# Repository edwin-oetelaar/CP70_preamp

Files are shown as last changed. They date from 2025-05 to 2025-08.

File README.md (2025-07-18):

# Yamaha CP70 Electric Grand Piano - 72 Channel Pre-amplifier Project

https://www.pomeindhoven.nl/

Paviljoen Ongehoorde Muziek
Vestdijk 25 - 5611 CA
Eindhoven

## Project Overview

This repository contains the KiCad project files, documentation, and design decisions for a custom-built 72-channel pre-amplifier designed for a Yamaha CP70 electric grand piano. This project is an open-source initiative developed in collaboration with [Paviljoen Ongehoorde Muziek (POM)](https://www.pomeindhoven.nl/) in Eindhoven, Netherlands, as part of an art project.

The primary goal of this pre-amplifier is to individually buffer and potentially amplify the signals from each of the 72 string pickups of the CP70, providing a high-quality, low-noise output output signal for further amplification to 72 speakers.

**Repository URL:** [https://github.com/edwin-oetelaar/CP70_preamp/tree/main](https://github.com/edwin-oetelaar/CP70_preamp/tree/main)

## Image of the piano

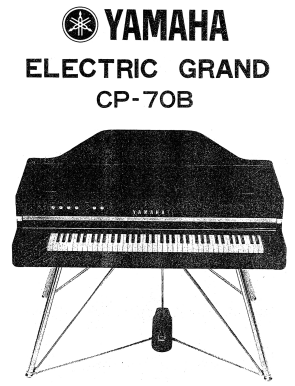
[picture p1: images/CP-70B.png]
piano


## Background

The Yamaha CP70 is an iconic electric grand piano known for its unique sound, derived from real strings and hammers combined with a piezo pickup system.
This project aims to provide a modern, high-fidelity replacement, with 72 separate output channels as an alternative pre-amplifier system.

This pre-amp is designed with the following considerations:
*   **High Input Impedance:** To accurately capture the full tonal character of the CP70 pickups without loading them down.
*   **Low Noise Performance:** Essential for a clean signal, especially with 72 individual channels.
*   **Sufficient Headroom:** To handle the potentially large signal swings from the pickups.
*   **Individual Channel Processing:** Each pickup receives its own pre-amplifier stage.
*   **Modularity:** For ease of assembly, testing, and maintenance.
*   **Open Source:** All design files and documentation are publicly available to encourage learning, modification, accessibility.

## Project Status

[ **TODO: Update this section regularly, e.g., In Design, Prototyping, Tested, In Use** ]

*   Current Version: [e.g., v0.1 - Initial Design]
*   Key Milestones:
    *   [x] Initial schematic design complete.
    *   [x] PCB layout for [16]-channel module complete.
    *   [x] PCB ordered
    *   [x] parts ordered
    *   [ ] First prototype(s) built and tested.
    *   [ ] Full 72-channel system assembled.
    *   [ ] Integration with the CP70 at Paviljoen Ongehoorde Muziek.

## Design Files and Documentation

This repository is structured to include:

*   **/kicad_project:** Contains the KiCad schematic and PCB layout files.
    *   `CP70_preamp.kicad_pro` - Main KiCad project file.
    *   `CP70_preamp.kicad_sch` - Main schematic file.
    *   `CP70_preamp.kicad_pcb` - Main PCB layout file (or individual module files).
    *   `libraries/` - Custom schematic symbols and PCB footprints, if any.
    *   `out1/` - Gerber files for PCB manufacturing (to be added when ready). (file out1.zip sent to JLCPCB)
    *   `bom/` - Bill of Materials (to be added).
*   **/documentation:**
    *   `design_decisions.md` - Detailed explanation of the design choices, component selection, and rationale.
    *   `specifications.md` - Target specifications for the pre-amplifier.
    *   `testing_procedure.md` - (To be added) How to test individual modules and the full system.
    *   Images, block diagrams, and other supporting documents.
*   **/images:** Schematics, photos of prototypes, etc.
*   `README.md` - This file.

# image of version 0.1 printed circuit board

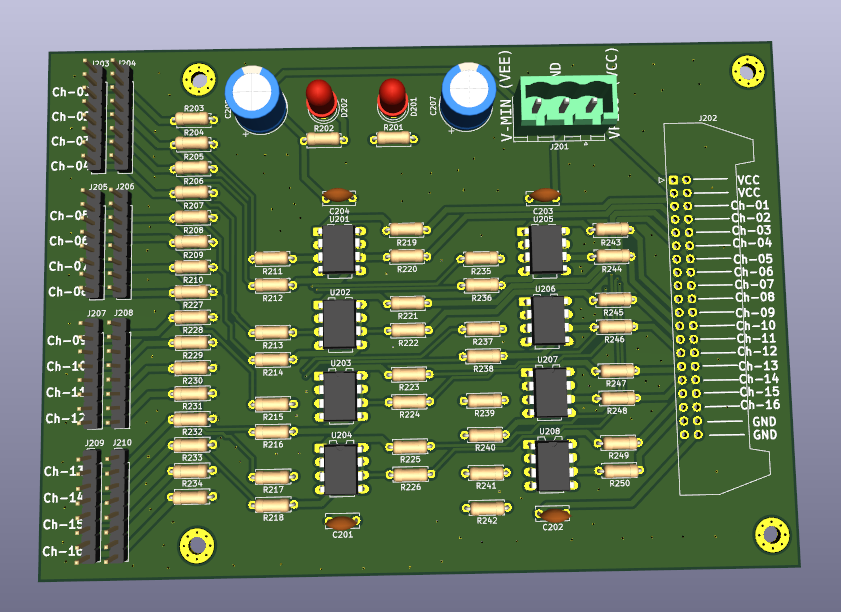
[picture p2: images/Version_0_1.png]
pcb0.1


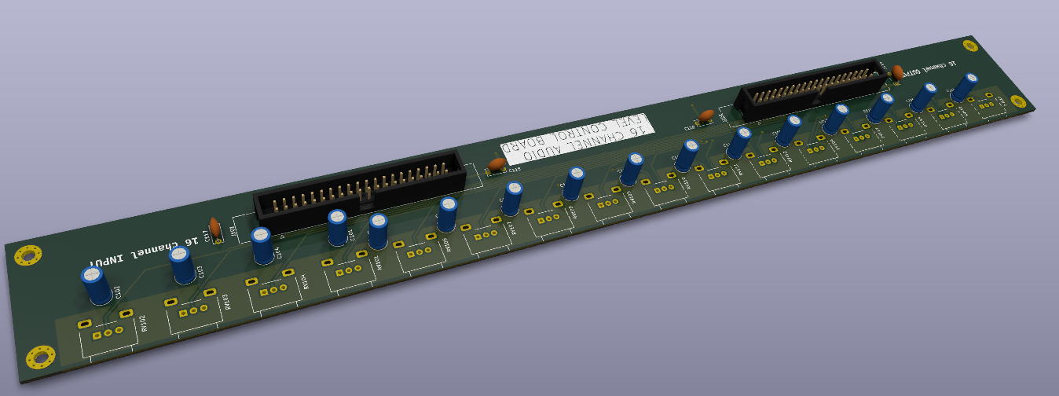
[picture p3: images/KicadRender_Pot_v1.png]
pcbPot0.1

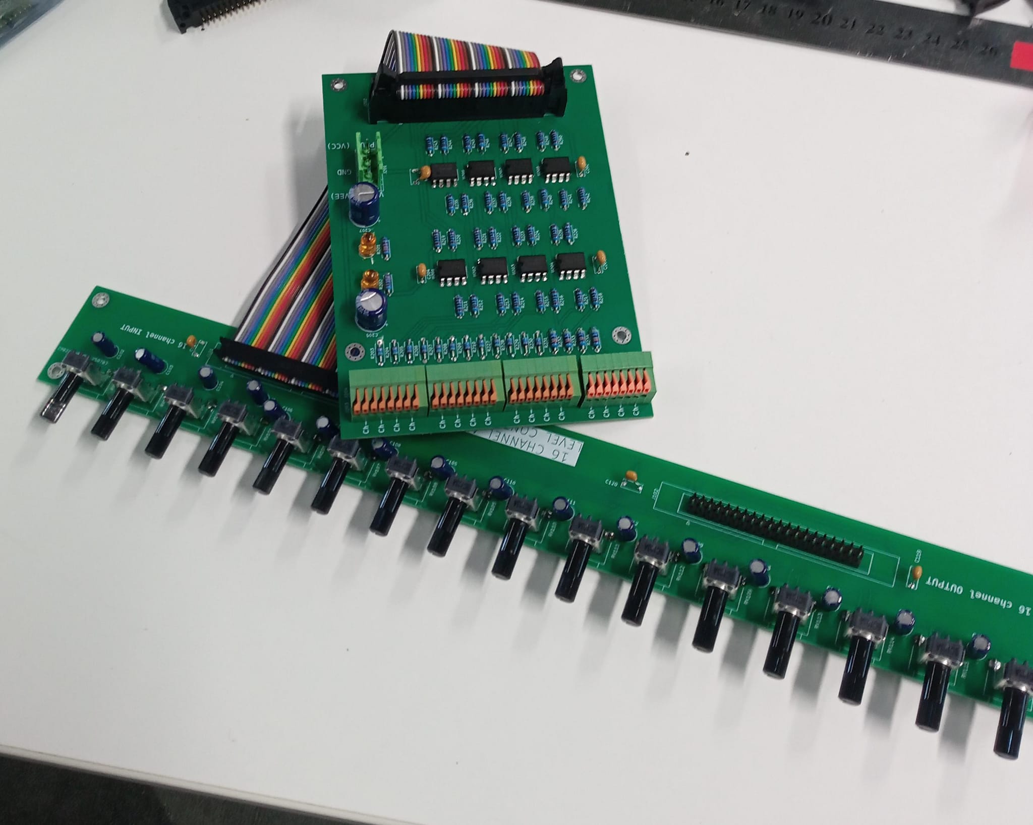
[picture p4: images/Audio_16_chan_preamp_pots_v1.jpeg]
pcb_built_v1


## Key Design Aspects (Summary)

*   **Number of Channels:** 72 (one for each pickup)
*   **Input Stage:** High-impedance buffer for each channel.
    *   Target Input Impedance: 470K Ω
    *   Expected Pickup Output: Up to 45V peak-to-peak in 1 M (requiring input attenuation).
*   **Operational Amplifier:** [e.g., TL072 or similar, specify your choice and link to design_decisions.md]
*   **Power Supply:** Symmetrical (e.g., +/-15V or +/-18V)
*   **Gain:** [e.g., Unity gain buffer, or variable gain via potentiometer - specify and link to design_decisions.md]

More detailed information on architecture, component choices, and trade-offs can be found in `/documentation/design_decisions.md`.

## Getting Started / How to Use

1.  **Clone the repository:**
    ```bash
    git clone https://github.com/edwin-oetelaar/CP70_preamp.git
    cd CP70_preamp
    ```
2.  **Open in KiCad:** Open the `CP70_preamp.kicad_pro` file in KiCad (Latest version).
3.  **Review Schematics and PCB Layout:** Explore the design in the KiCad schematic editor and PCB editor.
4.  **Check Documentation:** Read through the `design_decisions.md` and other documents for a deeper understanding.

## Contributing

This is an open-source project, and contributions or suggestions are welcome! If you have ideas, find bugs, or want to contribute to the design:

1.  **Fork the repository.**
2.  **Create a new branch** for your feature or bug fix.
3.  **Make your changes.**
4.  **Submit a Pull Request** with a clear description of your changes.

You can also open an [Issue](https://github.com/edwin-oetelaar/CP70_preamp/issues) to report bugs or suggest improvements.

## Collaboration

This project is in proud collaboration with:

**Paviljoen Ongehoorde Muziek (POM)**
Vestdijk 25 - 5611 CA Eindhoven
[https://www.pomeindhoven.nl/](https://www.pomeindhoven.nl/)

The pre-amplifier is intended for use in an art project hosted at POM.

## License

This project is licensed under the [MIT License](LICENSE.md) - see the LICENSE.md file for details.

## Contact

For questions or discussions regarding this project, you can contact:
*   Edwin van den Oetelaar - Leave a message in the issue tracker or google my name/email 
*   Or open an issue on this GitHub repository.

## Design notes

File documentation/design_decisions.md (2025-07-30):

# Design Decisions for the CP70 72-Channel Pre-amplifier

**by : Edwin van den Oetelaar**

This document outlines the key design decisions made during the development of the 72-channel pre-amplifier and associated power amplification for the Yamaha CP70 electric grand piano.

## Table of Contents

- [Design Decisions for the CP70 72-Channel Pre-amplifier](#design-decisions-for-the-cp70-72-channel-pre-amplifier)
  - [Table of Contents](#table-of-contents)
  - [1. Overall System Architecture](#1-overall-system-architecture)
  - [2. Pre-amplifier Design Philosophy: Serviceability and Technology Choice](#2-pre-amplifier-design-philosophy-serviceability-and-technology-choice)
  - [3. Pre-amplifier Modularity and Channel Distribution](#3-pre-amplifier-modularity-and-channel-distribution)
  - [4. Front Panel Potentiometer Integration](#4-front-panel-potentiometer-integration)
  - [5. Pre-amplifier Interconnects and Signal Cabling](#5-pre-amplifier-interconnects-and-signal-cabling)
  - [6. Pre-amplifier Power Supply System](#6-pre-amplifier-power-supply-system)
  - [7. Power Amplification Stage](#7-power-amplification-stage)
  - [8. Pre-amplifier Circuit Design (Per Channel)](#8-pre-amplifier-circuit-design-per-channel)
  - [9. Component Selection (Pre-amplifier)](#9-component-selection-pre-amplifier)
  - [System Block Diagram (Mermaid JS - Updated)](#system-block-diagram-mermaid-js---updated)

---

## 1. Overall System Architecture

The system comprises several key stages:
1.  **Pickup Interface:** 72 individual pickups from the Yamaha CP70.
2.  **Pre-amplification:** 72 dedicated pre-amplifier channels to buffer, (optionally) amplify, and provide gain control for each pickup.
3.  **Signal Output:** Buffered signals from the pre-amplifiers are routed out of the piano.
4.  **Power Amplification:** Off-the-shelf Class-D amplifier modules to drive speakers (details below).
5.  **Power Supplies:** Separate, dedicated power supply systems for the pre-amplifiers and power amplifiers.

## 2. Pre-amplifier Design Philosophy: Serviceability and Technology Choice

A core principle for the pre-amplifier design is **serviceability and repairability using standard tools and readily available components.**

*   **Technology Choice:** Through-Hole Technology (THT) will be used exclusively for the pre-amplifier PCBs. This includes THT resistors, capacitors, and IC sockets.
*   **Op-amp Sockets:** All operational amplifiers on the pre-amplifier boards will be socketed. This allows for easy replacement of op-amps without requiring specialized SMT rework equipment (like hot air stations or microscopes).
*   **PCB Material:** Standard double-sided FR4 PCB material will be used.
*   **Potentiometers:** THT potentiometers will be used for front-panel gain control.

This approach ensures that an electronics engineer or skilled technician with standard soldering equipment can maintain and repair the pre-amplifier system effectively.

## 3. Pre-amplifier Modularity and Channel Distribution

The 72 pre-amplifier channels will be distributed across **five (5) identical pre-amplifier Printed Circuit Board (PCB) modules.**

*   Each PCB module will host **sixteen (16) pre-amplifier channels.**
*   This results in a total of 5 modules * 16 channels/module = **80 available pre-amplifier channels.**
*   This provides **8 spare channels** for immediate replacement or future use.

## 4. Front Panel Potentiometer Integration

Individual gain control for each of the 72 active channels will be provided by THT potentiometers mounted on a front panel.

*   **Panel Dimensions:** Approximately 38 cm (width) x 8 cm (height).
*   **Potentiometer Count:** 80. (for each pre-amp channel)
*   **Connection:** Wiring from the potentiometers to the respective pre-amplifier channels on the PCB modules will be required.

## 5. Pre-amplifier Interconnects and Signal Cabling

**Output Signal Cabling (from Pre-amp Modules to External Interface):**

*   **Cable Type:** 40-pin IDC (Insulation-Displacement Connector) ribbon cables will be used *primarily for signal transport*.
*   **Distribution across 5 Cables:** Each of the 5 pre-amplifier modules will route its 16 output signals via one 40-pin ribbon cable.
    *   **Signal Allocation per Cable:** 16 channels * 2 wires/channel (signal + signal ground/return) = 32 wires.
    *   **Remaining Wires per 40-pin Cable:** 40 - 32 = 8 wires. These can be used for additional ground connections or left as spares, but **will not carry main power.**

## 6. Pre-amplifier Power Supply System

A dedicated, robust power supply system will provide symmetrical power (e.g., +/-15V) to the five pre-amplifier PCB modules.

*   **Power Supply Board:** A custom power supply PCB will be designed.
    *   **Technology:** Based on proven linear regulator technology: Transformer -> Diode Bridge Rectifier -> Bulk Filter Capacitors -> Multiple pairs of 7815 (+15V) and 7915 (-15V) linear voltage regulators.
    *   **Outputs:** The power supply board will provide multiple (at least 5, one for each pre-amp module) regulated +/-15V outputs. Each output will be capable of supplying one pre-amp module.
*   **Power Connectors to Pre-amp Modules:**
    *   **Type:** Standard industrial pluggable terminal block connectors.
    *   **Style:** 3-pole (for +Vcc, -Vee, AGND).
    *   **Pitch:** 5.08 mm (e.g., "Combicon" style or similar).
    *   Each pre-amplifier module PCB will have a corresponding 3-pole female connector to receive power.
*   **Rationale:** Separating power distribution from signal cables (ribbon cables) improves noise immunity and allows for more robust power delivery using appropriate gauge wires and connectors.

## 7. Power Amplification Stage

The power amplification stage will utilize off-the-shelf Class-D amplifier modules.

*   **Amplifier Module Choice:** "Chip Original TPA3118 60W DC 12V-24V" modules (commonly available from suppliers like AliExpress) will be purchased in bulk.
*   **Power Output:** Each module is rated for up to 60W (though actual output will depend on supply voltage and load).
*   **Power Supply for Amplifiers:**
    *   A separate 24V DC power supply system will be used for these Class-D modules.
    *   Considering the total power (estimated < 300W for all channels), this might be implemented as a single larger 24V supply or potentially **split into five (5) smaller, independent 24V DC power supplies**, one for each group of power amplifiers corresponding to a pre-amp module's outputs. This can offer better isolation and fault tolerance.
*   **Mounting/Integration Board for TPA3118 Modules:**
    *   To avoid messy point-to-point wiring to the numerous TPA3118 modules, a **custom "motherboard" or "carrier board" PCB** will be designed.
    *   This carrier board will provide:
        *   Sockets or designated mounting points for multiple TPA3118 modules (e.g., 16 per carrier board, aligning with the pre-amp module channel count).
        *   Input connectors to receive the buffered signals from the pre-amplifier ribbon cables.
        *   Output connectors for speakers.
        *   Power distribution and connectors for the 24V DC supply to each TPA3118 module.
    *   This approach significantly improves assembly neatness, reliability, and serviceability of the power amplifier stage.

## 8. Pre-amplifier Circuit Design (Per Channel)

*   [ Placeholder - Details of the THT op-amp circuit, input attenuation, gain stage, etc. ]*

## 9. Component Selection (Pre-amplifier)

*   **Op-amps:** Socketed, THT dual or quad op-amps (e.g., TL072/TL074 or modern equivalents with good audio performance and appropriate voltage ratings).
*   **Resistors:** THT, 1% metal film for signal path.
*   **Capacitors:** THT. Film capacitors for audio coupling (good bi-polar electrolithic caps were chosen), electrolytic/tantalum for power supply bulk filtering, ceramic for local IC decoupling.
*   **Potentiometers:** THT, panel mount, audio taper.
*   **Connectors:**
    *   Inputs from Pickups:  https://www.farnell.com/datasheets/2995445.pdf PCB Spring Type Terminal Blocks (2.54mm pitch)
    *   Outputs to Ribbon Cables: 40-pin IDC male headers on PCB.
    *   Power Input: 3-pole, 5.08mm pitch pluggable terminal block female connector on PCB.
*   [ Placeholder - Other specific components. Refer to Bill of Materials (BOM). ]*

---

## System Block Diagram (Mermaid JS - Updated)

```mermaid
   graph TD
   subgraph Piano_System
        PUs[72 CP70 Pickups] -->|Raw Signals| PreAmp_PCBs
        PreAmp_PCBs -.->|Gain Control Wiring| Pots_Panel
        Pots_Panel -->|User Input| User(User Adjusts Gain)   
        subgraph PreAmp_PCBs["5x Pre-Amplifier PCB Modules (16 THT channels each, Socketed Op-amps)"]
            direction LR
            PCB1[Module 1: 16 Pre-amps]
            PCB2[Module 2: 16 Pre-amps]
            PCB3[Module 3: 16 Pre-amps]
            PCB4[Module 4: 16 Pre-amps]
            PCB5[Module 5: 16 Pre-amps]
        end

        Pots_Panel["Front Panel: 72 THT Potentiometers (38x8cm)"]

        PreAmp_PCBs -->|"Buffered Signals (16 ch/cable via 40-pin Ribbon)"| PowerAmp_Carrier_Boards

        PreAmp_PowerSupply_Board["Pre-amp Power Supply Board (Transformer, Rectifiers, 7815/7915 Regulators)"]
        PreAmp_PowerSupply_Board -->|"Regulated +/-15V (x5 outputs via 3-pole Connectors)"| PreAmp_PCBs
    end

    subgraph Power_Amplification_And_Output
        direction TB
        PowerAmp_Carrier_Boards["5x Power Amp Carrier Boards"]
        subgraph PowerAmp_Carrier_Boards_Details["Details per Carrier Board (example)"]
            direction LR
            Input_From_PreAmp_Ribbon["Ribbon Cable Input (16ch)"] --> TPA_Modules_Mounted
            TPA_Modules_Mounted["16x TPA3118 Class-D Modules (Socketed/Mounted)"] --> Speaker_Outputs[Speaker Outputs]
            Pots_Panel -->|Adjusted levels|TPA_Modules_Mounted 
            PA_Power_Input[24V DC Power Input] --> TPA_Modules_Mounted
        end

        PA_Power_Supplies["5x 24V DC Power Supplies (or single large PSU)"]
        PA_Power_Supplies --> PA_Power_Input

        Speaker_Outputs --> Speakers[Speakers]
    end

    style PUs fill:#22d,stroke:#333,stroke-width:2px
    style PreAmp_PCBs fill:#bbf,stroke:#333,stroke-width:2px
    style Pots_Panel fill:#22d,stroke:#333,stroke-width:2px
    style PreAmp_PowerSupply_Board fill:#orange,stroke:#333,stroke-width:2px
    style PowerAmp_Carrier_Boards fill:#22d,stroke:#333,stroke-width:2px
    style PA_Power_Supplies fill:#orange,stroke:#333,stroke-width:2px
    style Speakers fill:#grey,stroke:#333,stroke-width:2px
```

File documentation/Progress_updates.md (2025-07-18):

---
title: "CP70 Pre-Amp Project Status Report"
date: [YYYY-MM-DD]
version: [vX.Y]
---

## 1. Project Overview  
**Background**  
The Yamaha CP70 is an iconic electric grand piano known for its unique sound, derived from real strings and hammers combined with a piezo pickup system. This project aims to provide a modern, high-fidelity replacement, with 72 separate output channels as an alternative pre-amplifier system.

**Key Objectives**
- High input impedance (470 kΩ) to preserve pickup characteristics
- Very-low noise floor (<20 nV/√Hz)
- Modular 16-channel PCB design
- Open-source hardware documentation

---

## 2. Current Progress  
### 2.1 Version Status
**Current Version**: [v0.3 - Prototype Validation]  
**Project Status**: [🟢 Prototyping | 🟡 Testing | 🔴 In Design]

### 2.2 Key Milestones  
| Milestone | Status | Last Updated |
|---|---|---|
| 16-channel PCB layout | ✅ Completed | 2025-06-10 |
| Input impedance validation | 🟡 In Progress | 2025-07-15 |
| Noise floor measurement | ❌ Pending | - |
| Full 72-channel assembly | ❌ Pending | - |

### 2.3 Technical Updates

**Design Progress**  
- Finalized 2-layer PCB stackup with dedicated ground plane 
- Implemented JFET-based input stage for impedance buffering
- Tested input stage, tested on CP70 pickups, OK (see images)
- Added per-channel gain adjustment (-inf to 0dB)
- designed and built PCB with 16 Audio Log Pots and 40 pin flat cables

**Component Selection**  
- Op-amps: TL072/TL052 (selected for 15nV/√Hz noise)
- Connectors: 3M 2.54mm pitch terminal blocks
- Power: ±15V rails with TL7815 TL7915 regulators

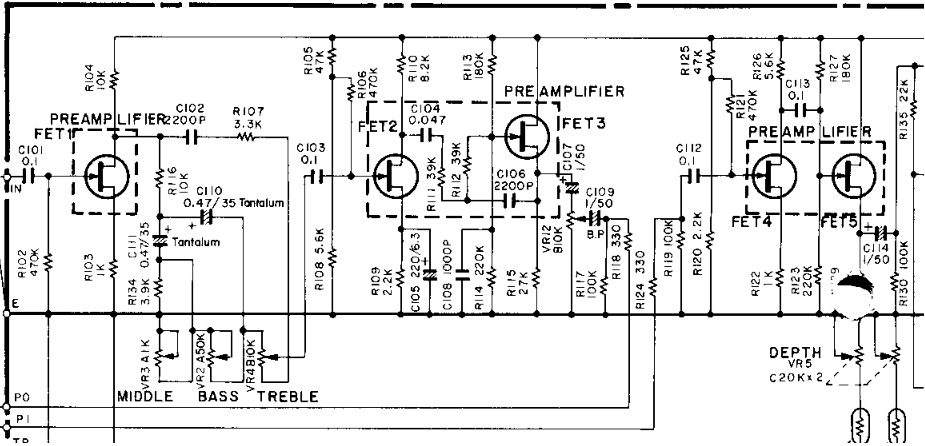
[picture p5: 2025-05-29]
images/cp70_preamp.jpg

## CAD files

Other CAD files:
kicad_project/CP70_line_flatcable/flatcable_PCB_dimensions.FCStd
kicad_project/CP70_line_flatcable/flatcable_PCB_dimensions.dxf

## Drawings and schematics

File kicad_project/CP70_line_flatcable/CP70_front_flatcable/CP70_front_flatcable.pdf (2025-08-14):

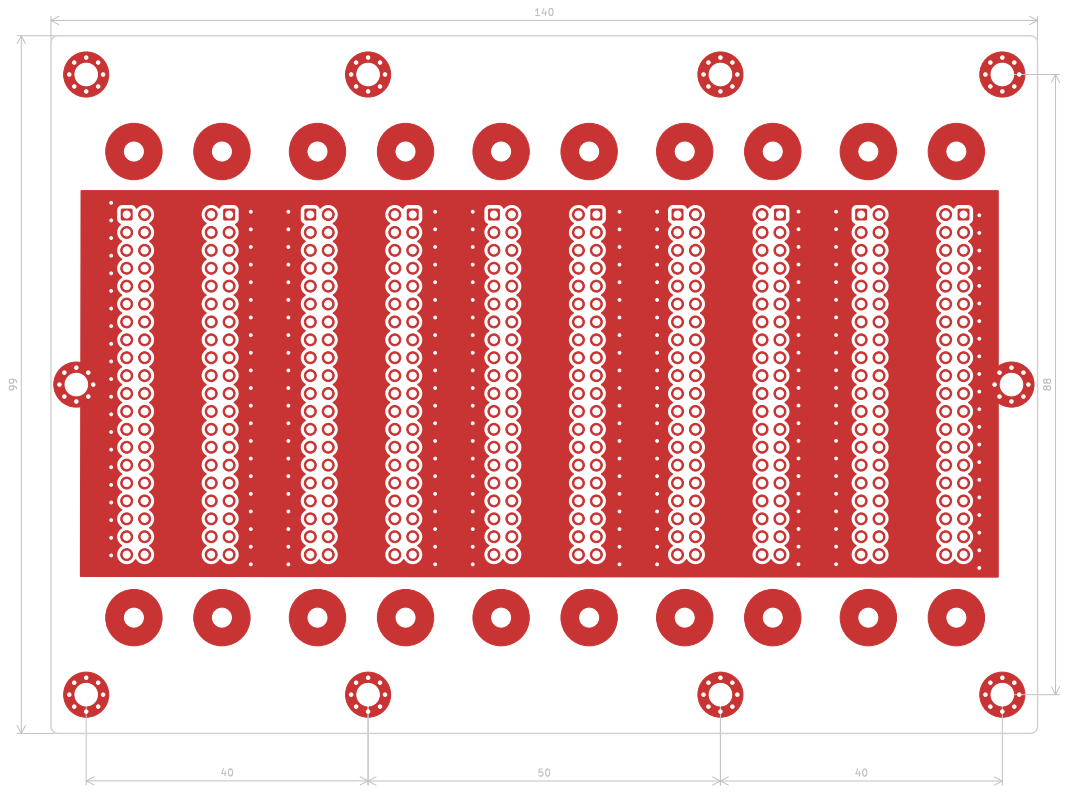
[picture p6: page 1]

Id: 1/9 Title: File: CP70_front_flatcable.kicad_pcb Sheet:

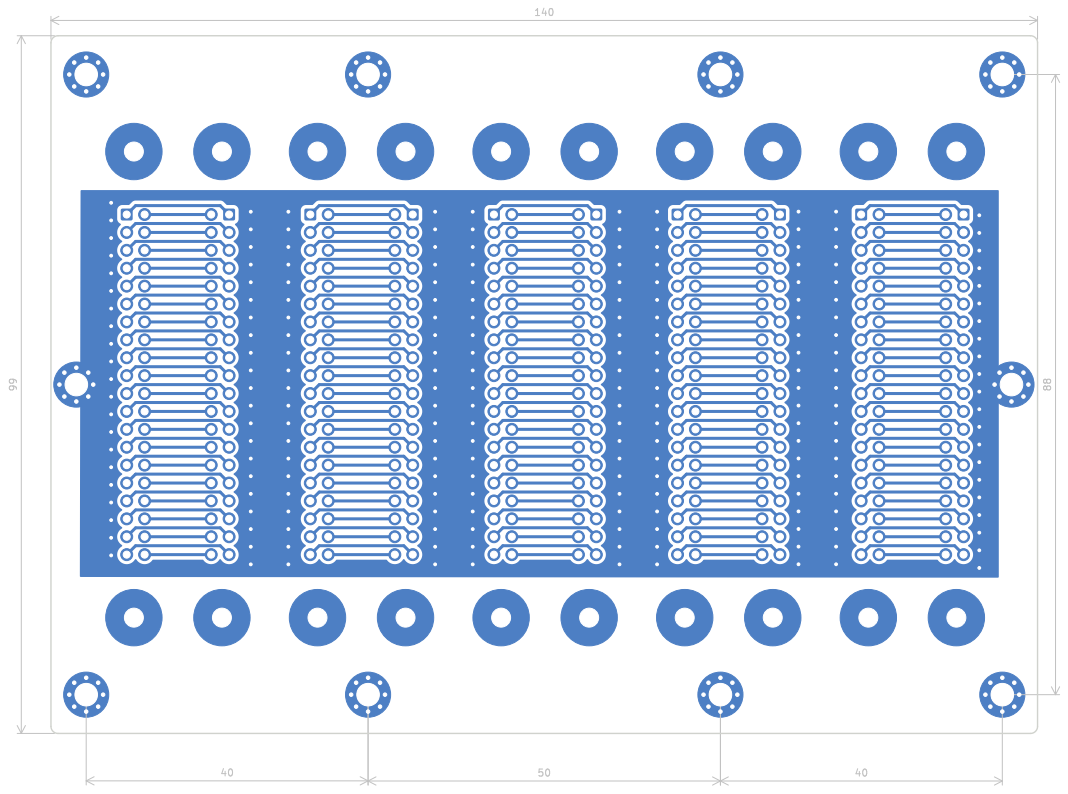
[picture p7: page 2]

Id: 2/9 Title: File: CP70_front_flatcable.kicad_pcb Sheet:

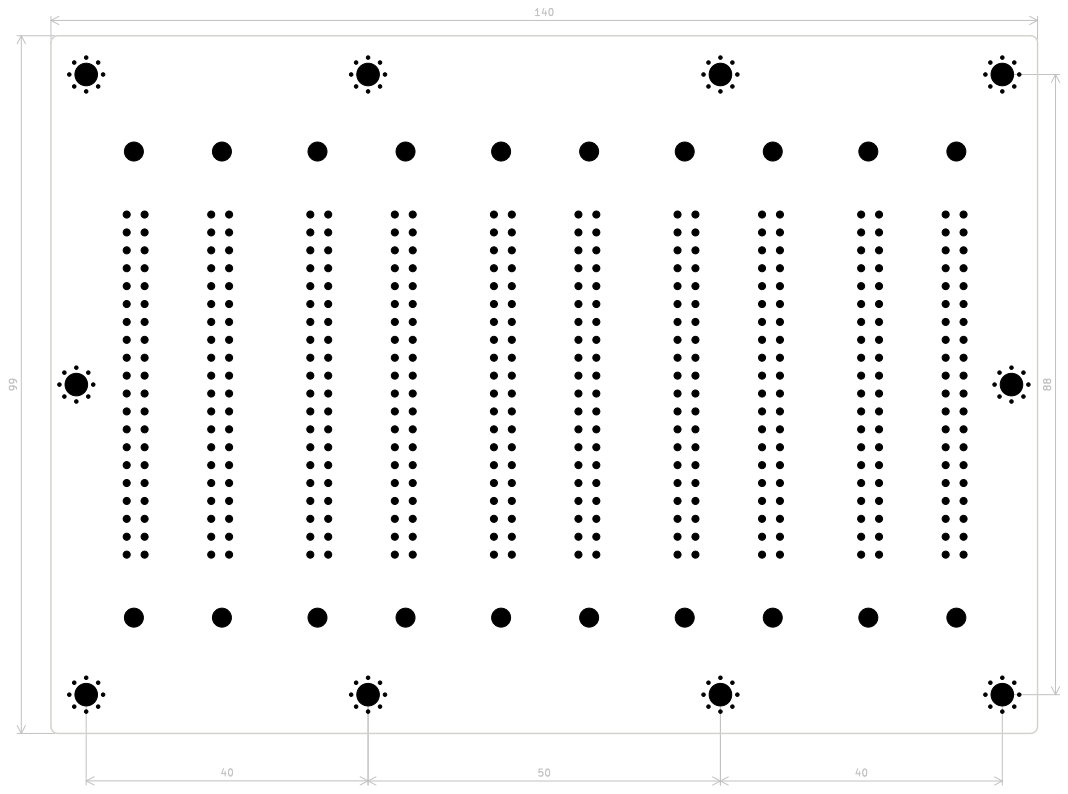
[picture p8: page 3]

Id: 3/9 Title: File: CP70_front_flatcable.kicad_pcb Sheet:

Id: 4/9 Title: File: CP70_front_flatcable.kicad_pcb Sheet:

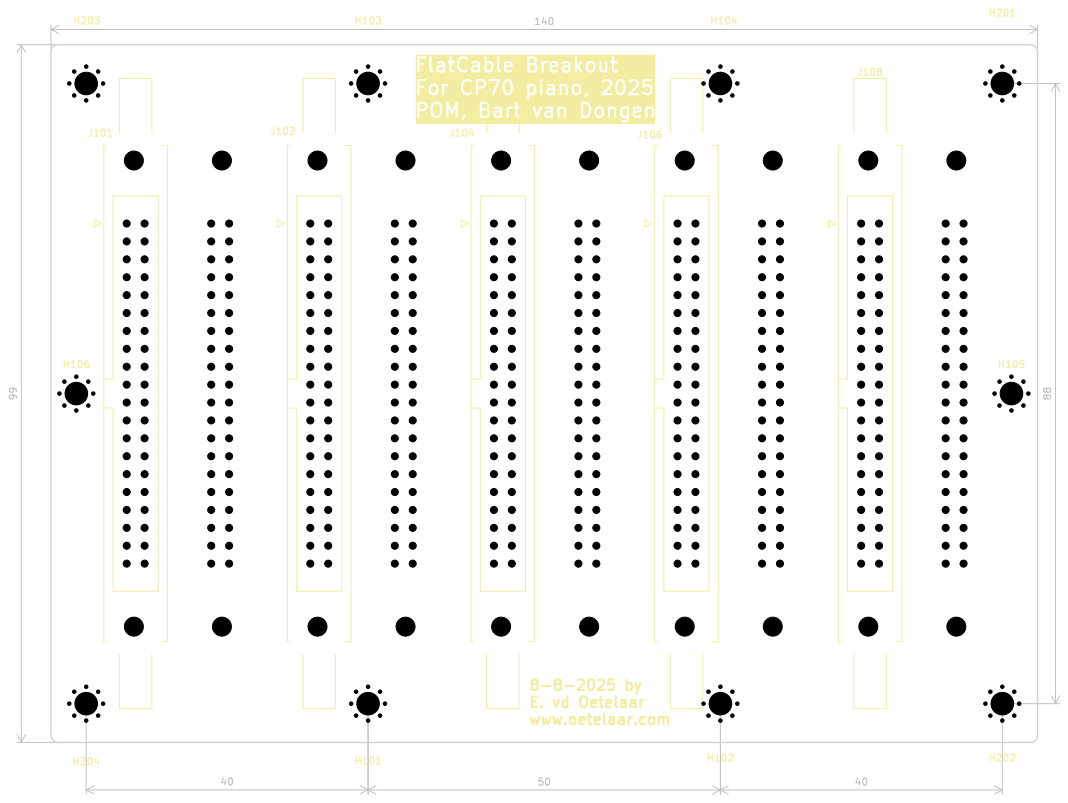
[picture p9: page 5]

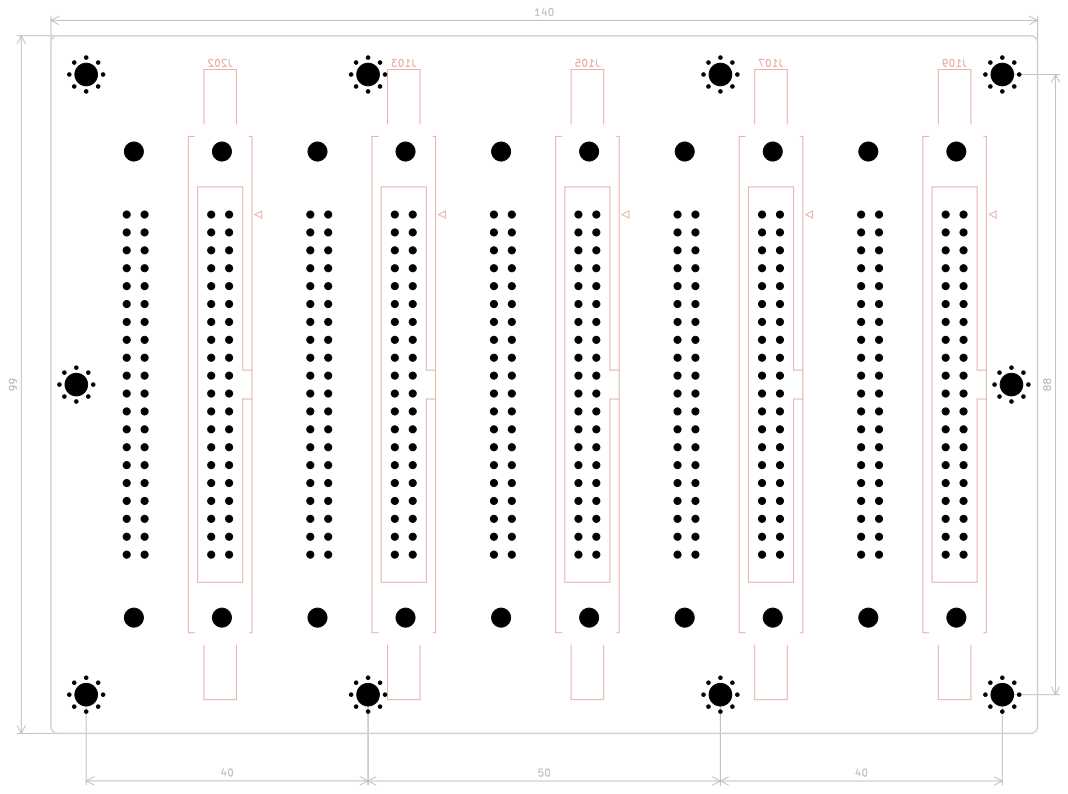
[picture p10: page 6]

Id: 6/9 Title: File: CP70_front_flatcable.kicad_pcb Sheet:

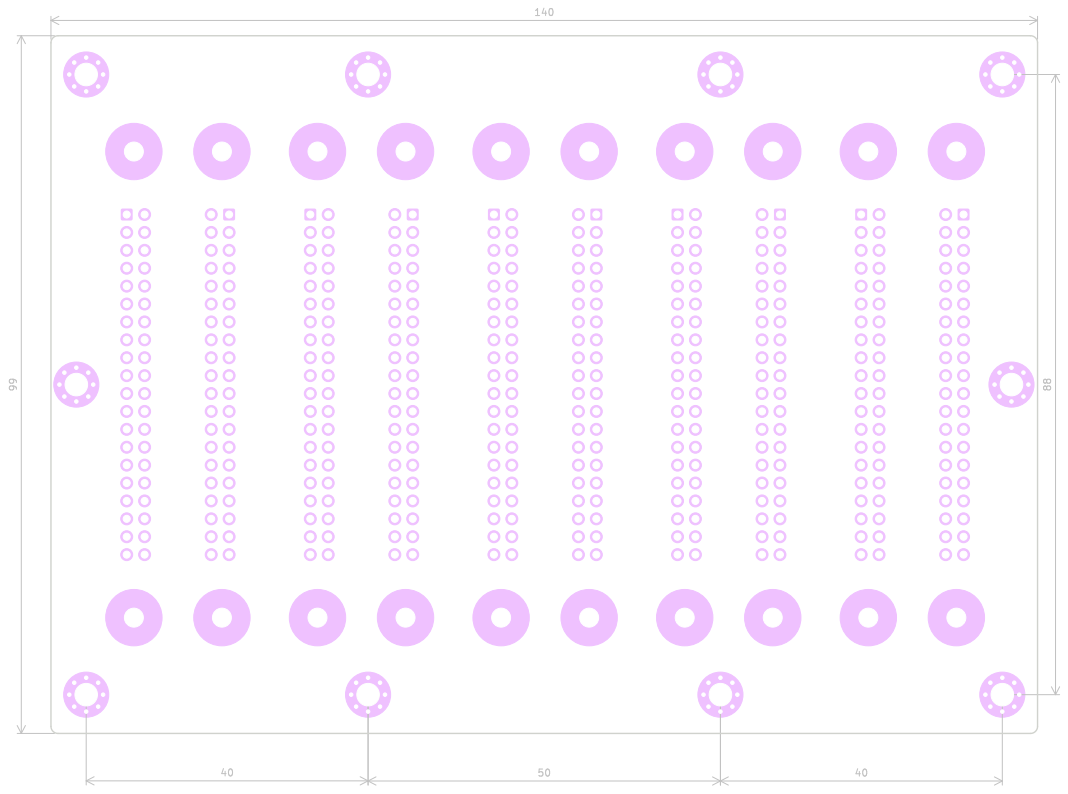
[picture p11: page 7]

Id: 7/9 Title: File: CP70_front_flatcable.kicad_pcb Sheet:

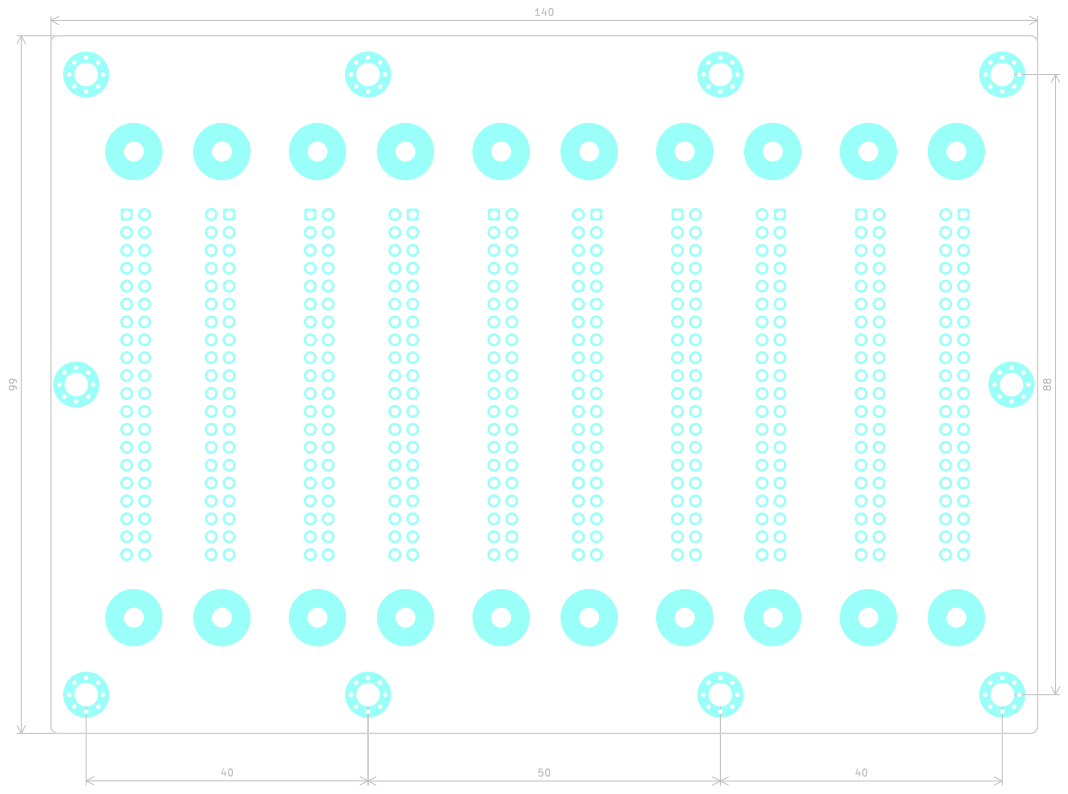
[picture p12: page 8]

Id: 8/9 Title: File: CP70_front_flatcable.kicad_pcb Sheet:

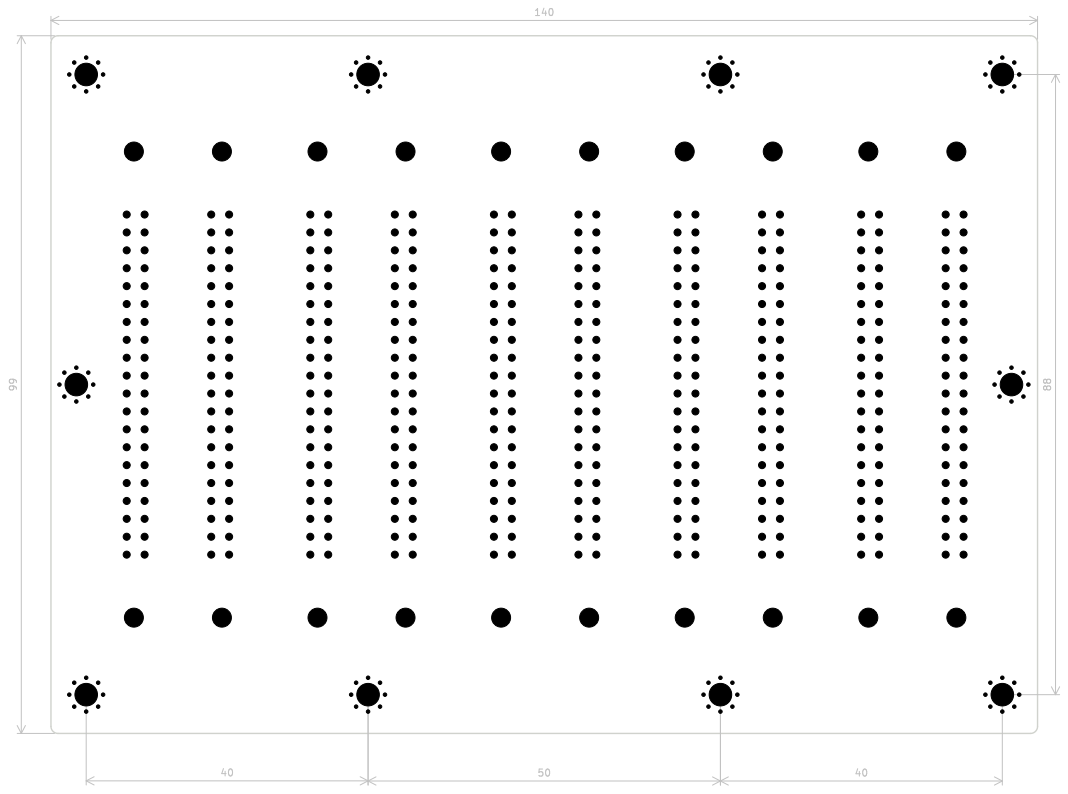
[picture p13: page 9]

Id: 9/9 Title: File: CP70_front_flatcable.kicad_pcb Sheet:

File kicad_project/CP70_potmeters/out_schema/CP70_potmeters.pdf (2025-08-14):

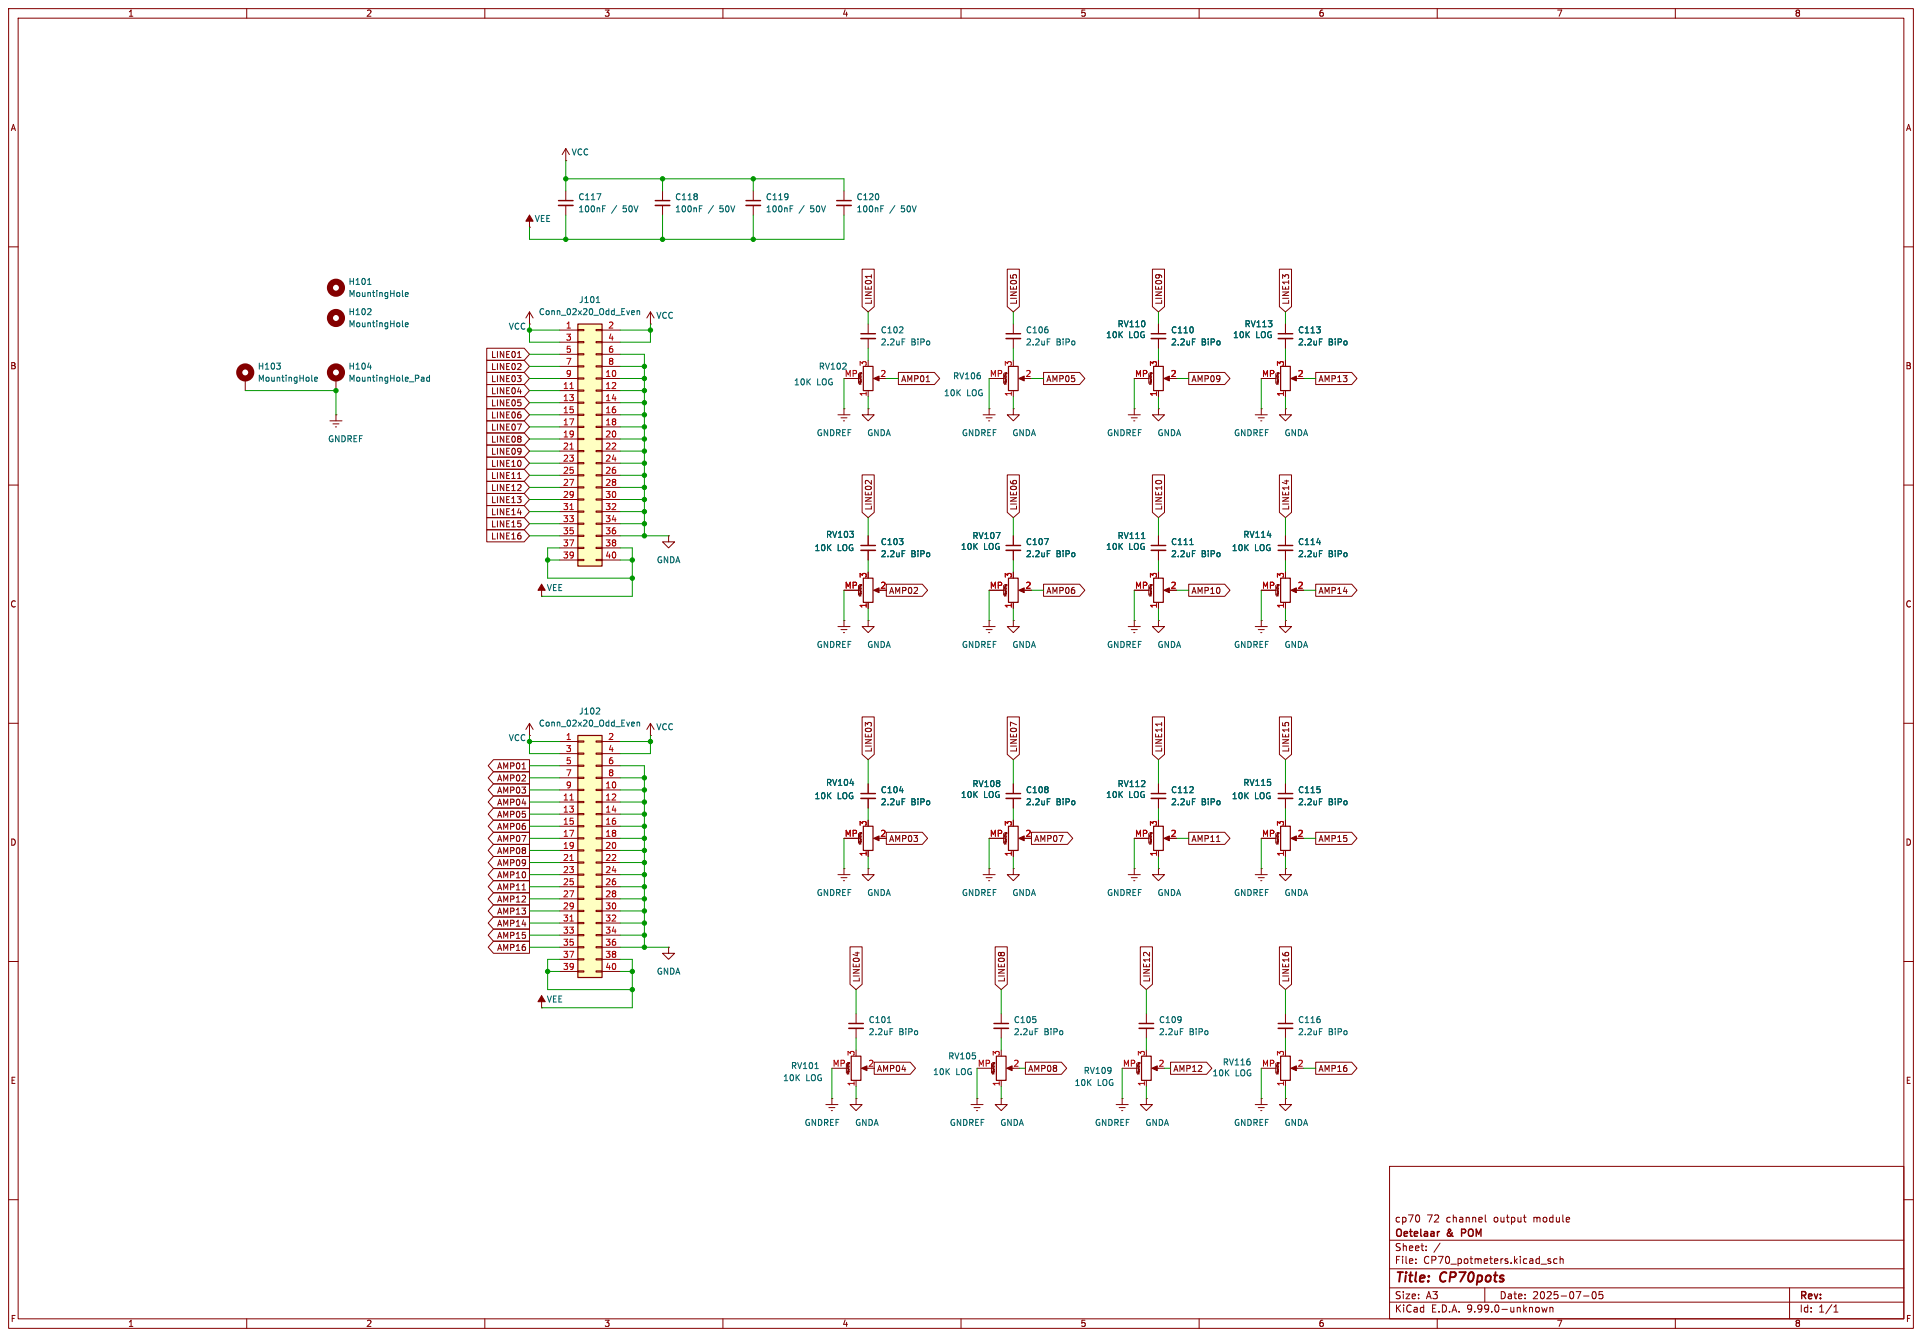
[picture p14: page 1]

GNDREF H102 MountingHole H101 MountingHole H104 MountingHole_Pad H103 MountingHole

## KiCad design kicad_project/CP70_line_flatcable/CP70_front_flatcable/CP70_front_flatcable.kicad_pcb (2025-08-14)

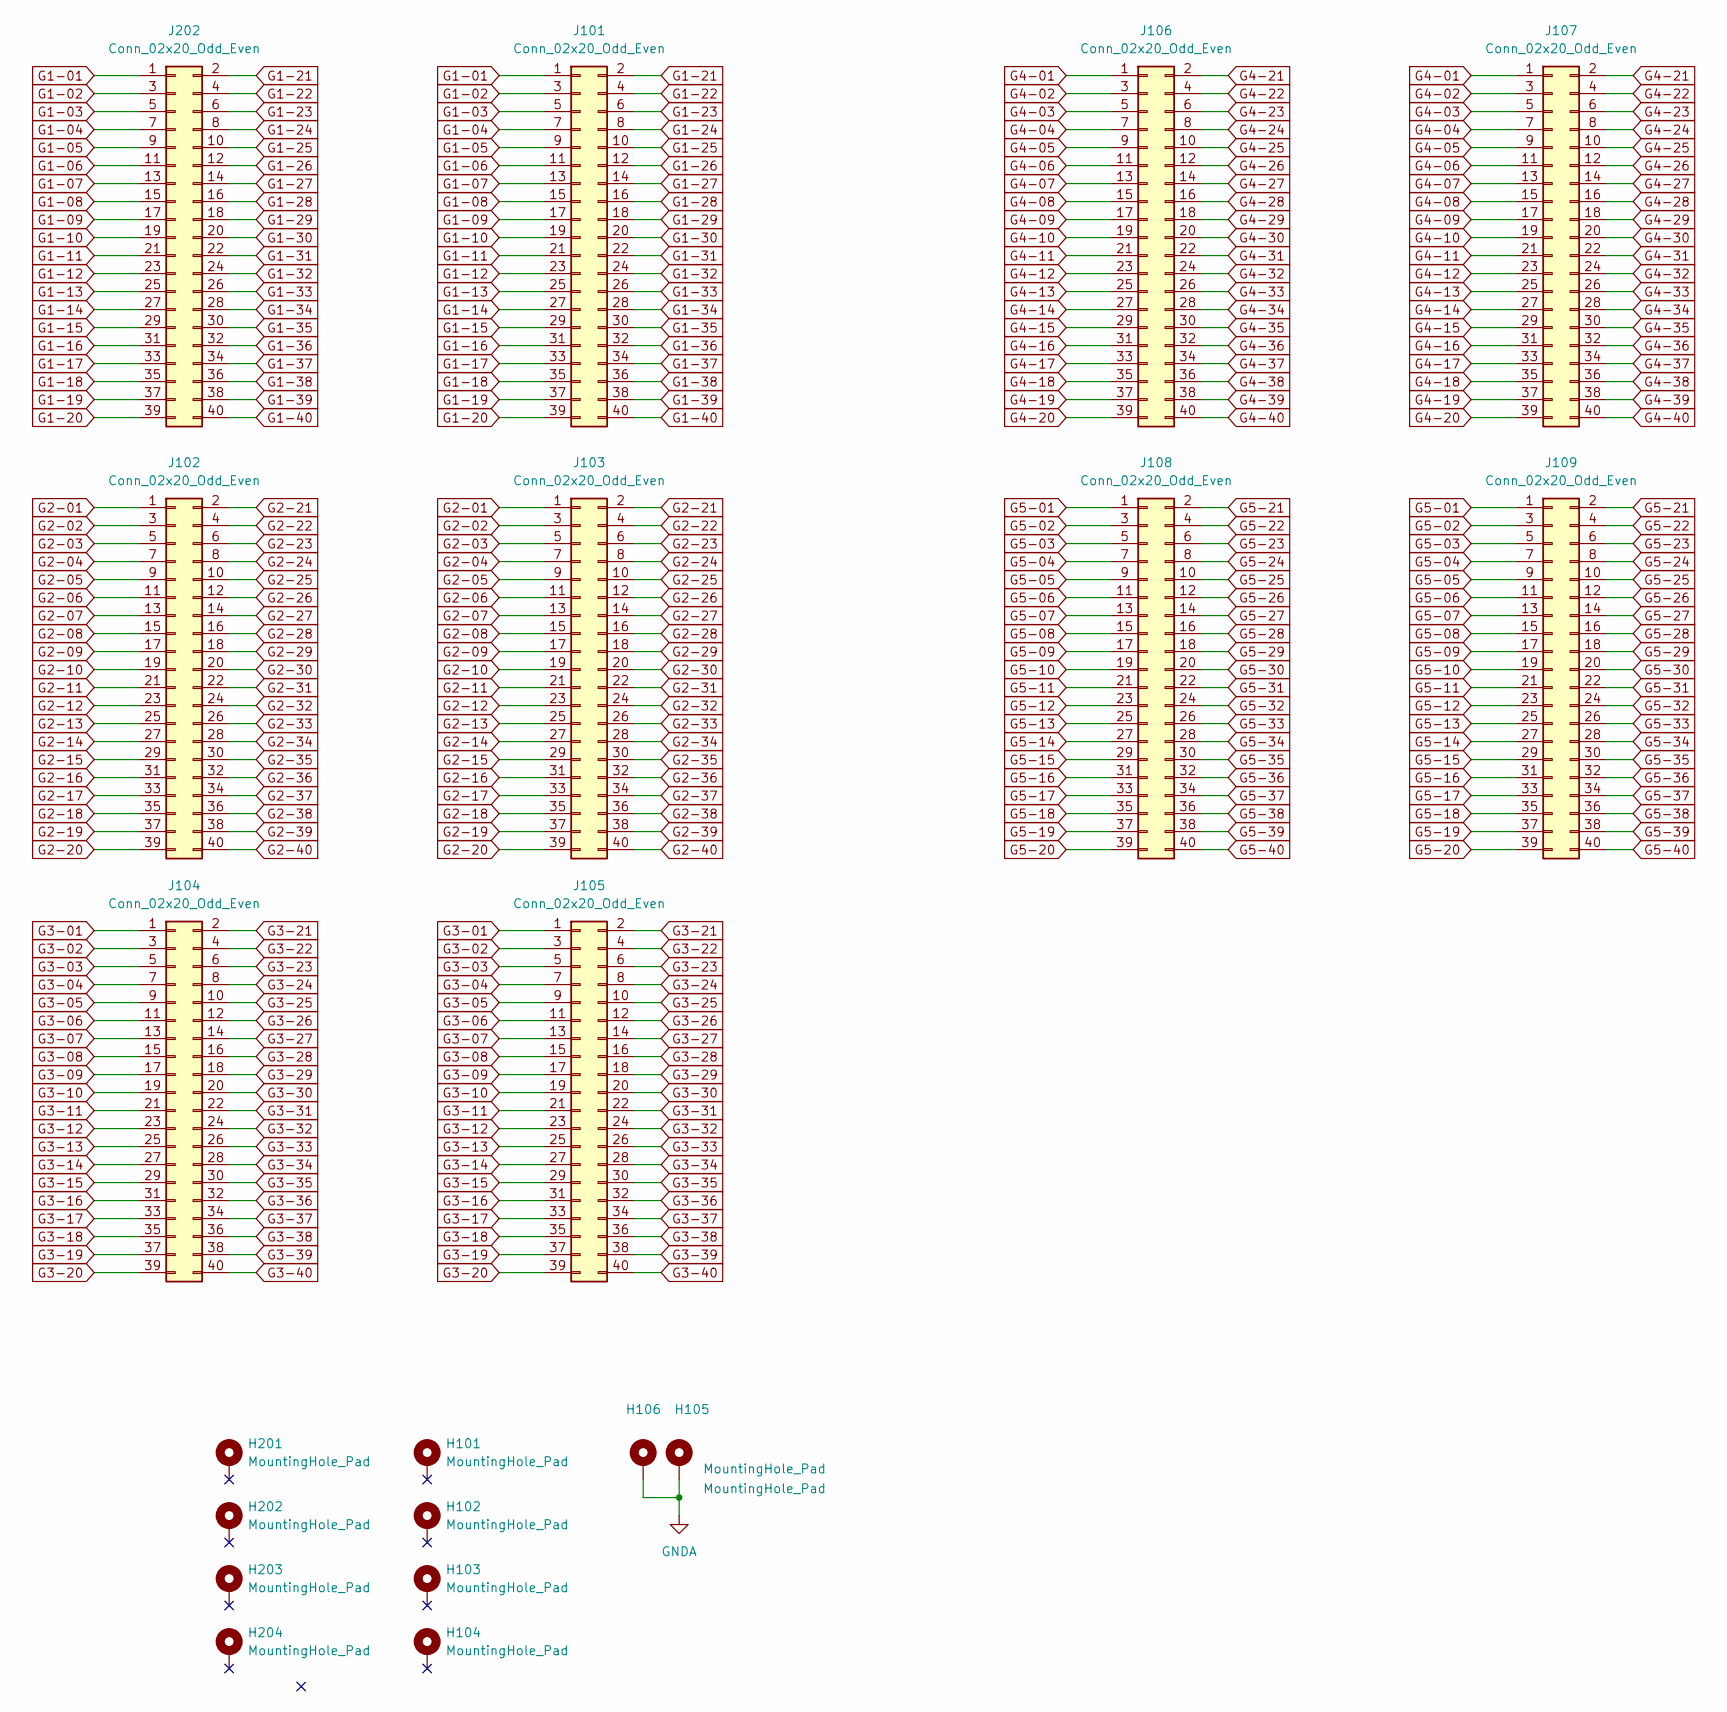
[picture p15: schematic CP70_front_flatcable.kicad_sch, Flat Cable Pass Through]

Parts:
H101, H102, H103, H104, H105, H106, H201, H202, H203, H204: MountingHole_Pad; MountingHole_3.2mm_M3_Pad_Via
J101, J102, J103, J104, J105, J106, J107, J108, J109, J202: Conn_02x20_Odd_Even; IDC-Header_2x20-1MP_P2.54mm_Latch9.5mm_Vertical

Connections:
G1-01: J101.1, J202.1
G1-02: J101.3, J202.3
G1-03: J101.5, J202.5
G1-04: J101.7, J202.7
G1-05: J101.9, J202.9
G1-06: J101.11, J202.11
G1-07: J101.13, J202.13
G1-08: J101.15, J202.15
G1-09: J101.17, J202.17
G1-10: J101.19, J202.19
G1-11: J101.21, J202.21
G1-12: J101.23, J202.23
G1-13: J101.25, J202.25
G1-14: J101.27, J202.27
G1-15: J101.29, J202.29
G1-16: J101.31, J202.31
G1-17: J101.33, J202.33
G1-18: J101.35, J202.35
G1-19: J101.37, J202.37
G1-20: J101.39, J202.39
G1-21: J101.2, J202.2
G1-22: J101.4, J202.4
G1-23: J101.6, J202.6
G1-24: J101.8, J202.8
G1-25: J101.10, J202.10
G1-26: J101.12, J202.12
G1-27: J101.14, J202.14
G1-28: J101.16, J202.16
G1-29: J101.18, J202.18
G1-30: J101.20, J202.20
G1-31: J101.22, J202.22
G1-32: J101.24, J202.24
G1-33: J101.26, J202.26
G1-34: J101.28, J202.28
G1-35: J101.30, J202.30
G1-36: J101.32, J202.32
G1-37: J101.34, J202.34
G1-38: J101.36, J202.36
G1-39: J101.38, J202.38
G1-40: J101.40, J202.40
G2-01: J102.1, J103.1
G2-02: J102.3, J103.3
G2-03: J102.5, J103.5
G2-04: J102.7, J103.7
G2-05: J102.9, J103.9
G2-06: J102.11, J103.11
G2-07: J102.13, J103.13
G2-08: J102.15, J103.15
G2-09: J102.17, J103.17
G2-10: J102.19, J103.19
G2-11: J102.21, J103.21
G2-12: J102.23, J103.23
G2-13: J102.25, J103.25
G2-14: J102.27, J103.27
G2-15: J102.29, J103.29
G2-16: J102.31, J103.31
G2-17: J102.33, J103.33
G2-18: J102.35, J103.35
G2-19: J102.37, J103.37
G2-20: J102.39, J103.39
G2-21: J102.2, J103.2
G2-22: J102.4, J103.4
G2-23: J102.6, J103.6
G2-24: J102.8, J103.8
G2-25: J102.10, J103.10
G2-26: J102.12, J103.12
G2-27: J102.14, J103.14
G2-28: J102.16, J103.16
G2-29: J102.18, J103.18
G2-30: J102.20, J103.20
G2-31: J102.22, J103.22
G2-32: J102.24, J103.24
G2-33: J102.26, J103.26
G2-34: J102.28, J103.28
G2-35: J102.30, J103.30
G2-36: J102.32, J103.32
G2-37: J102.34, J103.34
G2-38: J102.36, J103.36
G2-39: J102.38, J103.38
G2-40: J102.40, J103.40
G3-01: J104.1, J105.1
G3-02: J104.3, J105.3
G3-03: J104.5, J105.5
G3-04: J104.7, J105.7
G3-05: J104.9, J105.9
G3-06: J104.11, J105.11
G3-07: J104.13, J105.13
G3-08: J104.15, J105.15
G3-09: J104.17, J105.17
G3-10: J104.19, J105.19
G3-11: J104.21, J105.21
G3-12: J104.23, J105.23
G3-13: J104.25, J105.25
G3-14: J104.27, J105.27
G3-15: J104.29, J105.29
G3-16: J104.31, J105.31
G3-17: J104.33, J105.33
G3-18: J104.35, J105.35
G3-19: J104.37, J105.37
G3-20: J104.39, J105.39
G3-21: J104.2, J105.2
G3-22: J104.4, J105.4
G3-23: J104.6, J105.6
G3-24: J104.8, J105.8
G3-25: J104.10, J105.10
G3-26: J104.12, J105.12
G3-27: J104.14, J105.14
G3-28: J104.16, J105.16
G3-29: J104.18, J105.18
G3-30: J104.20, J105.20
G3-31: J104.22, J105.22
G3-32: J104.24, J105.24
G3-33: J104.26, J105.26
G3-34: J104.28, J105.28
G3-35: J104.30, J105.30
G3-36: J104.32, J105.32
G3-37: J104.34, J105.34
G3-38: J104.36, J105.36
G3-39: J104.38, J105.38
G3-40: J104.40, J105.40
G4-01: J106.1, J107.1
G4-02: J106.3, J107.3
G4-03: J106.5, J107.5
G4-04: J106.7, J107.7
G4-05: J106.9, J107.9
G4-06: J106.11, J107.11
G4-07: J106.13, J107.13
G4-08: J106.15, J107.15
G4-09: J106.17, J107.17
G4-10: J106.19, J107.19
G4-11: J106.21, J107.21
G4-12: J106.23, J107.23
G4-13: J106.25, J107.25
G4-14: J106.27, J107.27
G4-15: J106.29, J107.29
G4-16: J106.31, J107.31
G4-17: J106.33, J107.33
G4-18: J106.35, J107.35
G4-19: J106.37, J107.37
G4-20: J106.39, J107.39
G4-21: J106.2, J107.2
G4-22: J106.4, J107.4
G4-23: J106.6, J107.6
G4-24: J106.8, J107.8
G4-25: J106.10, J107.10
G4-26: J106.12, J107.12
G4-27: J106.14, J107.14
G4-28: J106.16, J107.16
G4-29: J106.18, J107.18
G4-30: J106.20, J107.20
G4-31: J106.22, J107.22
G4-32: J106.24, J107.24
G4-33: J106.26, J107.26
G4-34: J106.28, J107.28
G4-35: J106.30, J107.30
G4-36: J106.32, J107.32
G4-37: J106.34, J107.34
G4-38: J106.36, J107.36
G4-39: J106.38, J107.38
G4-40: J106.40, J107.40
G5-01: J108.1, J109.1
G5-02: J108.3, J109.3
G5-03: J108.5, J109.5
G5-04: J108.7, J109.7
G5-05: J108.9, J109.9
G5-06: J108.11, J109.11
G5-07: J108.13, J109.13
G5-08: J108.15, J109.15
G5-09: J108.17, J109.17
G5-10: J108.19, J109.19
G5-11: J108.21, J109.21
G5-12: J108.23, J109.23
G5-13: J108.25, J109.25
G5-14: J108.27, J109.27
G5-15: J108.29, J109.29
G5-16: J108.31, J109.31
G5-17: J108.33, J109.33
G5-18: J108.35, J109.35
G5-19: J108.37, J109.37
G5-20: J108.39, J109.39
G5-21: J108.2, J109.2
G5-22: J108.4, J109.4
G5-23: J108.6, J109.6
G5-24: J108.8, J109.8
G5-25: J108.10, J109.10
G5-26: J108.12, J109.12
G5-27: J108.14, J109.14
G5-28: J108.16, J109.16
G5-29: J108.18, J109.18
G5-30: J108.20, J109.20
G5-31: J108.22, J109.22
G5-32: J108.24, J109.24
G5-33: J108.26, J109.26
G5-34: J108.28, J109.28
G5-35: J108.30, J109.30
G5-36: J108.32, J109.32
G5-37: J108.34, J109.34
G5-38: J108.36, J109.36
G5-39: J108.38, J109.38
G5-40: J108.40, J109.40
GNDA: H105.1, H106.1

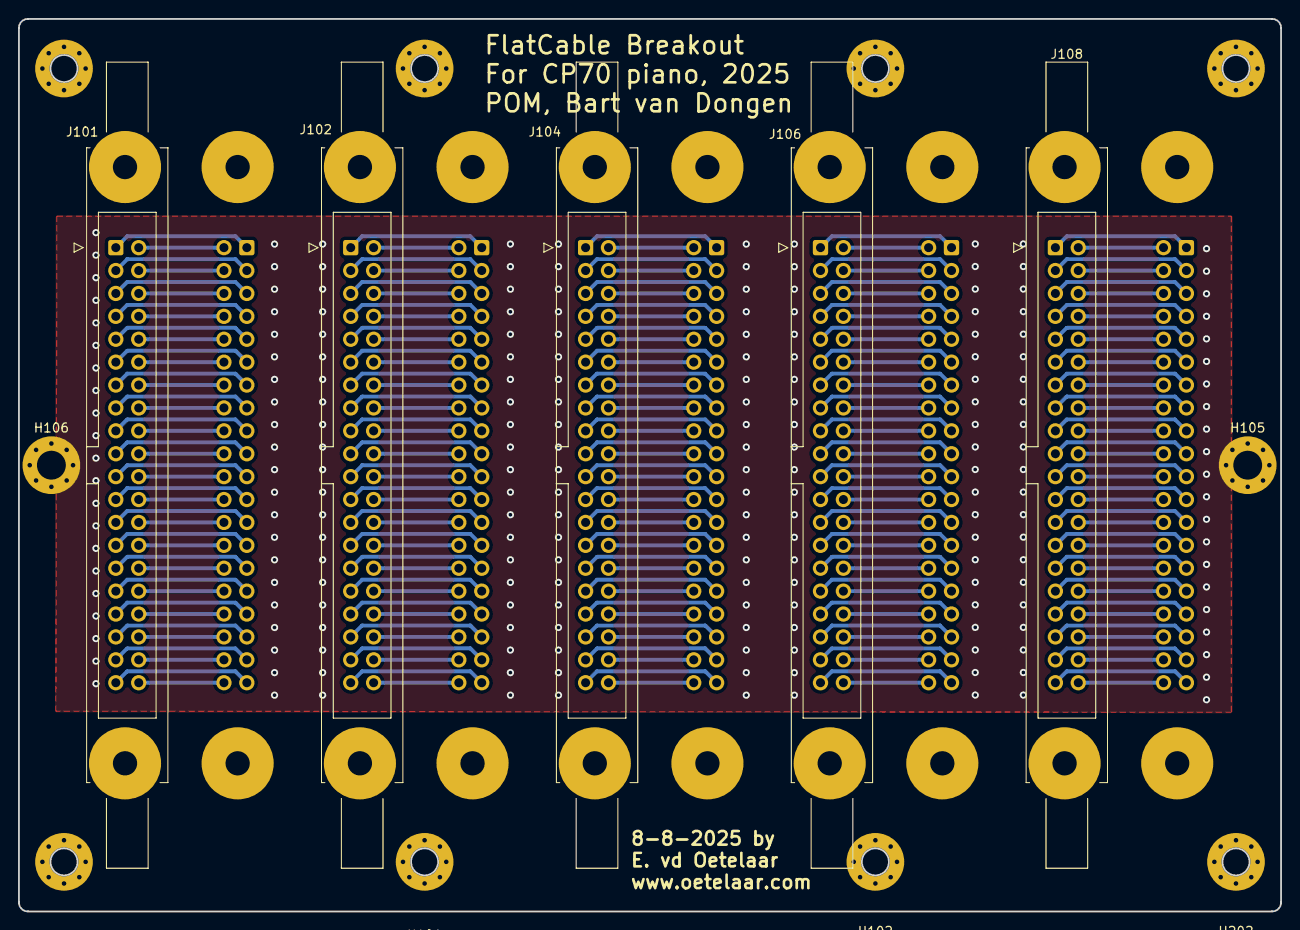
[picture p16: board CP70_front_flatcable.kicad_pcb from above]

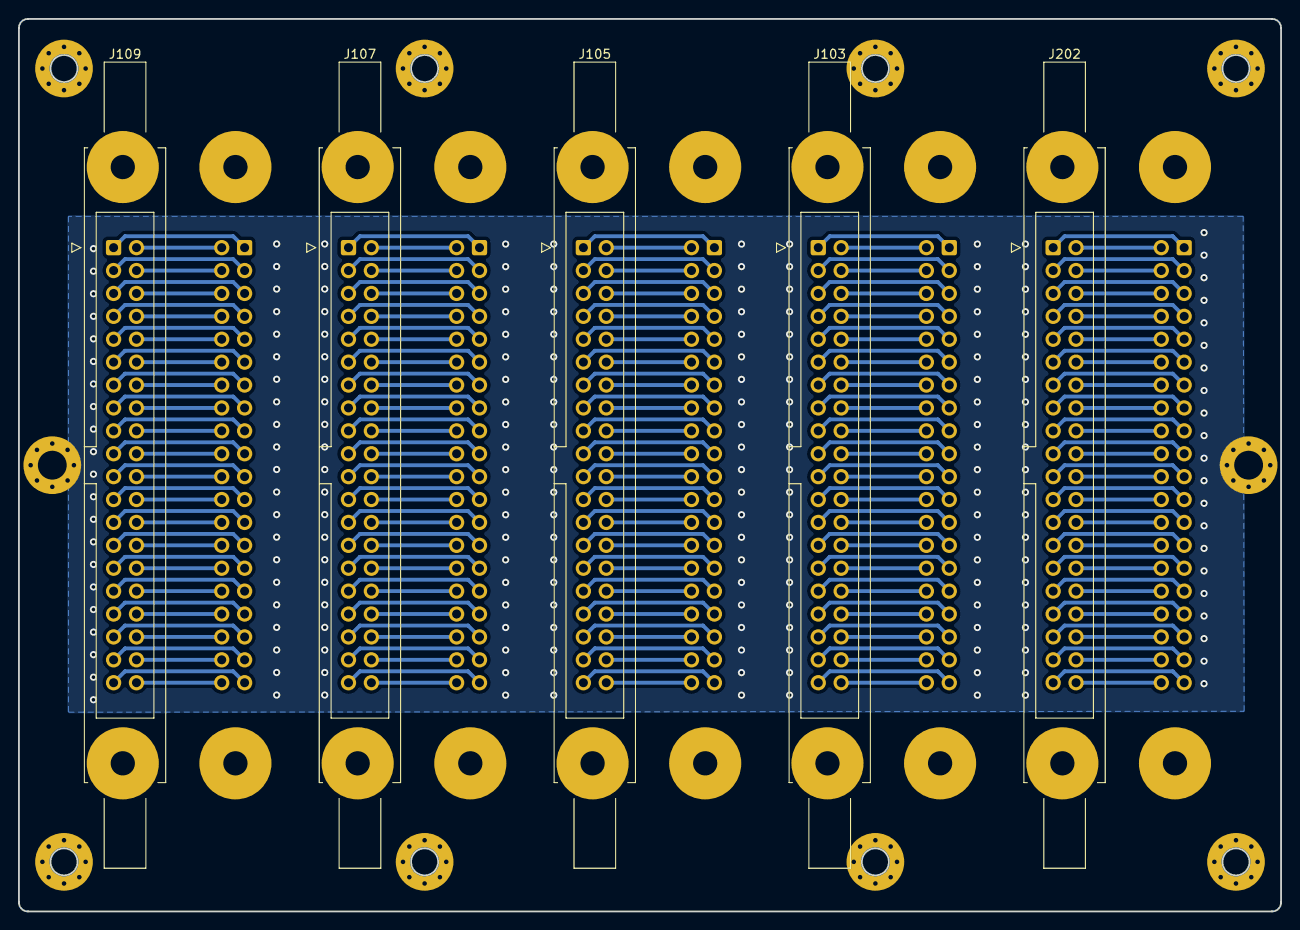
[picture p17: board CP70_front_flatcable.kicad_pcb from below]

Board: 2 copper layers, 140.0 x 99.0 mm, 20 parts (5 on the bottom side), 201 nets.

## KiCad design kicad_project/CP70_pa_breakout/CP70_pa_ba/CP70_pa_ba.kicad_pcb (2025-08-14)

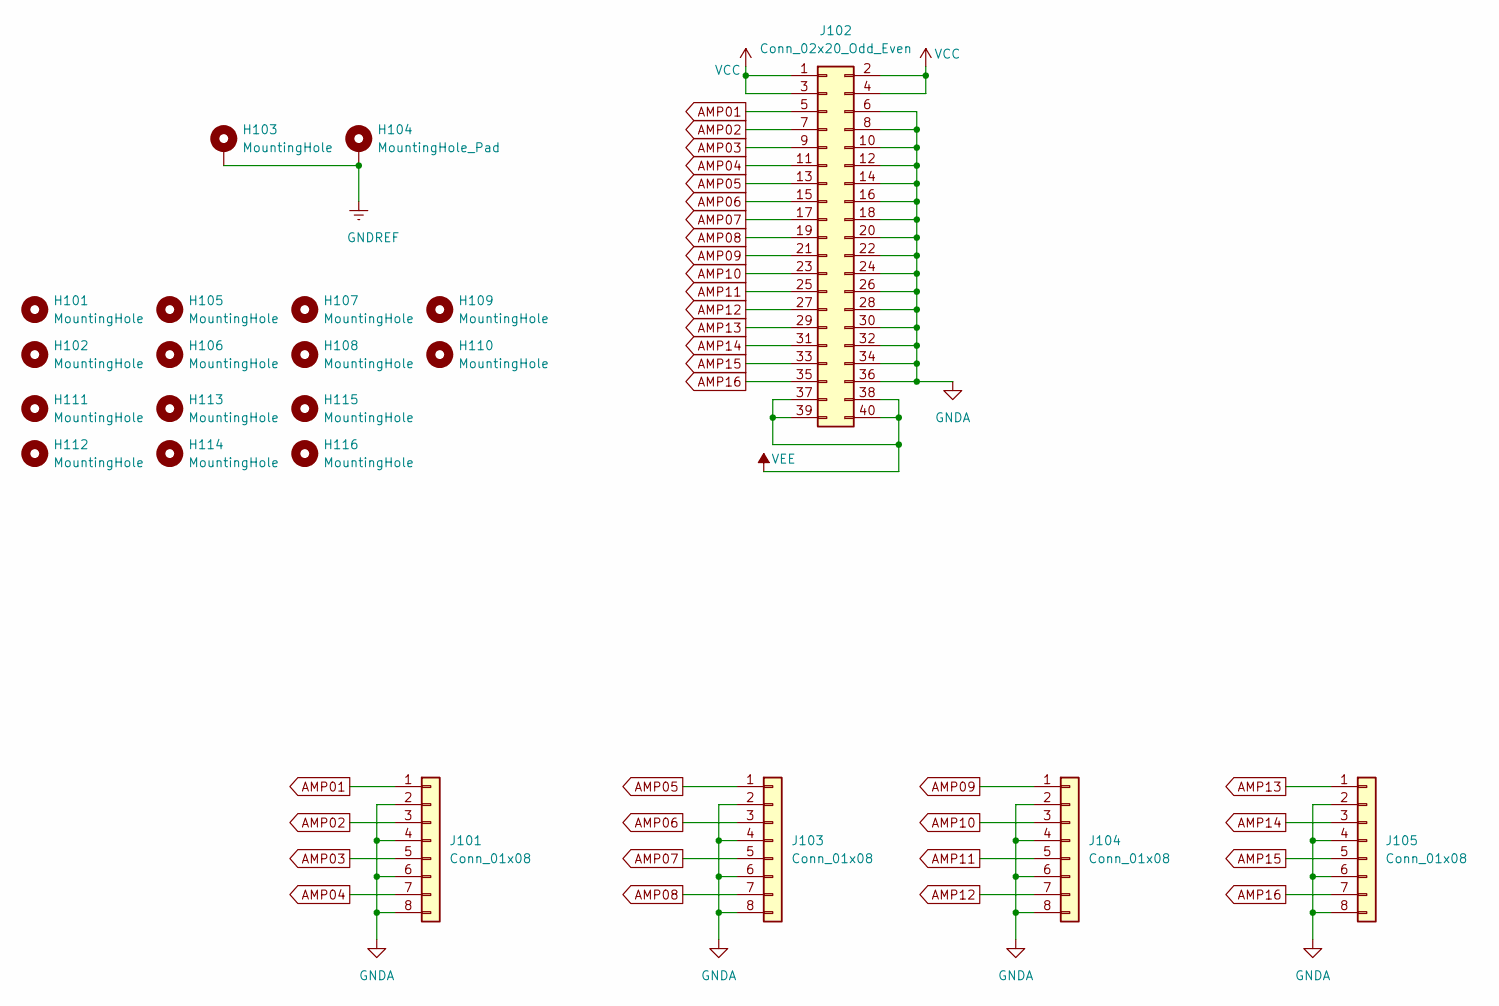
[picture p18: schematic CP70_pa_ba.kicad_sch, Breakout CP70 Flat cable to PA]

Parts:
H101, H102, H103, H105, H106, H107, H108, H109, H110, H111, H112, H113, H114, H115, H116: MountingHole; MountingHole_3.2mm_M3_Pad_Via
H104: MountingHole_Pad; MountingHole_3.2mm_M3_Pad_Via
J101, J103, J104, J105: Conn_01x08; KF141R-2.54-8
J102: Conn_02x20_Odd_Even; IDC-Header_2x20_P2.54mm_Latch_Vertical

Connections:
AMP01: J101.1, J102.5
AMP02: J101.3, J102.7
AMP03: J101.5, J102.9
AMP04: J101.7, J102.11
AMP05: J102.13, J103.1
AMP06: J102.15, J103.3
AMP07: J102.17, J103.5
AMP08: J102.19, J103.7
AMP09: J102.21, J104.1
AMP10: J102.23, J104.3
AMP11: J102.25, J104.5
AMP12: J102.27, J104.7
AMP13: J102.29, J105.1
AMP14: J102.31, J105.3
AMP15: J102.33, J105.5
AMP16: J102.35, J105.7
GNDA: J101.2, J101.4, J101.6, J101.8, J102.6, J102.8, J102.10, J102.12, J102.14, J102.16, J102.18, J102.20, J102.22, J102.24, J102.26, J102.28, J102.30, J102.32, J102.34, J102.36, J103.2, J103.4, J103.6, J103.8, J104.2, J104.4, J104.6, J104.8, J105.2, J105.4, J105.6, J105.8
GNDREF: H103.1, H104.1
VCC: J102.1, J102.2, J102.3, J102.4
VEE: J102.37, J102.38, J102.39, J102.40

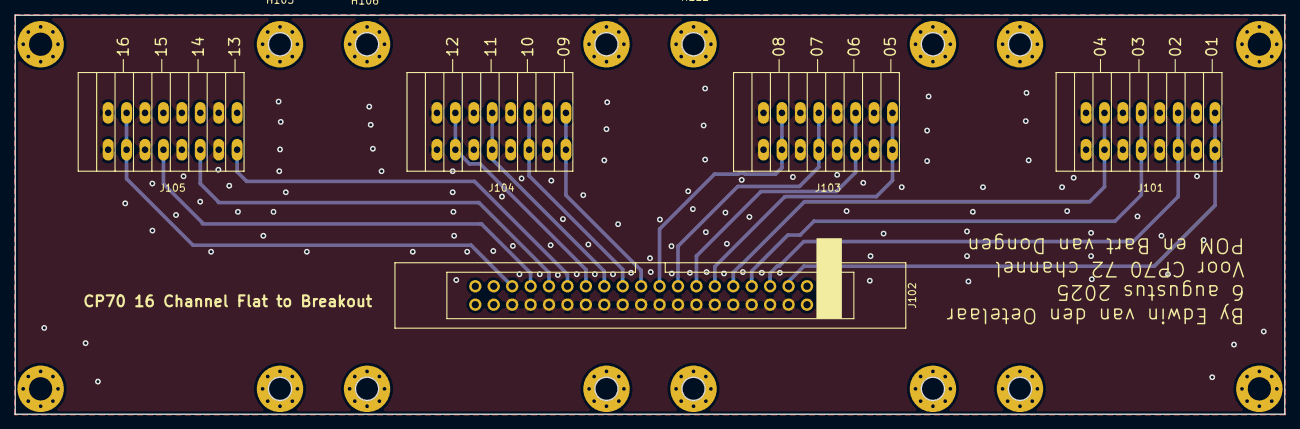
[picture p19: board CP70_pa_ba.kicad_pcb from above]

Board: 2 copper layers, 175.0 x 55.0 mm, 21 parts (0 on the bottom side), 20 nets.

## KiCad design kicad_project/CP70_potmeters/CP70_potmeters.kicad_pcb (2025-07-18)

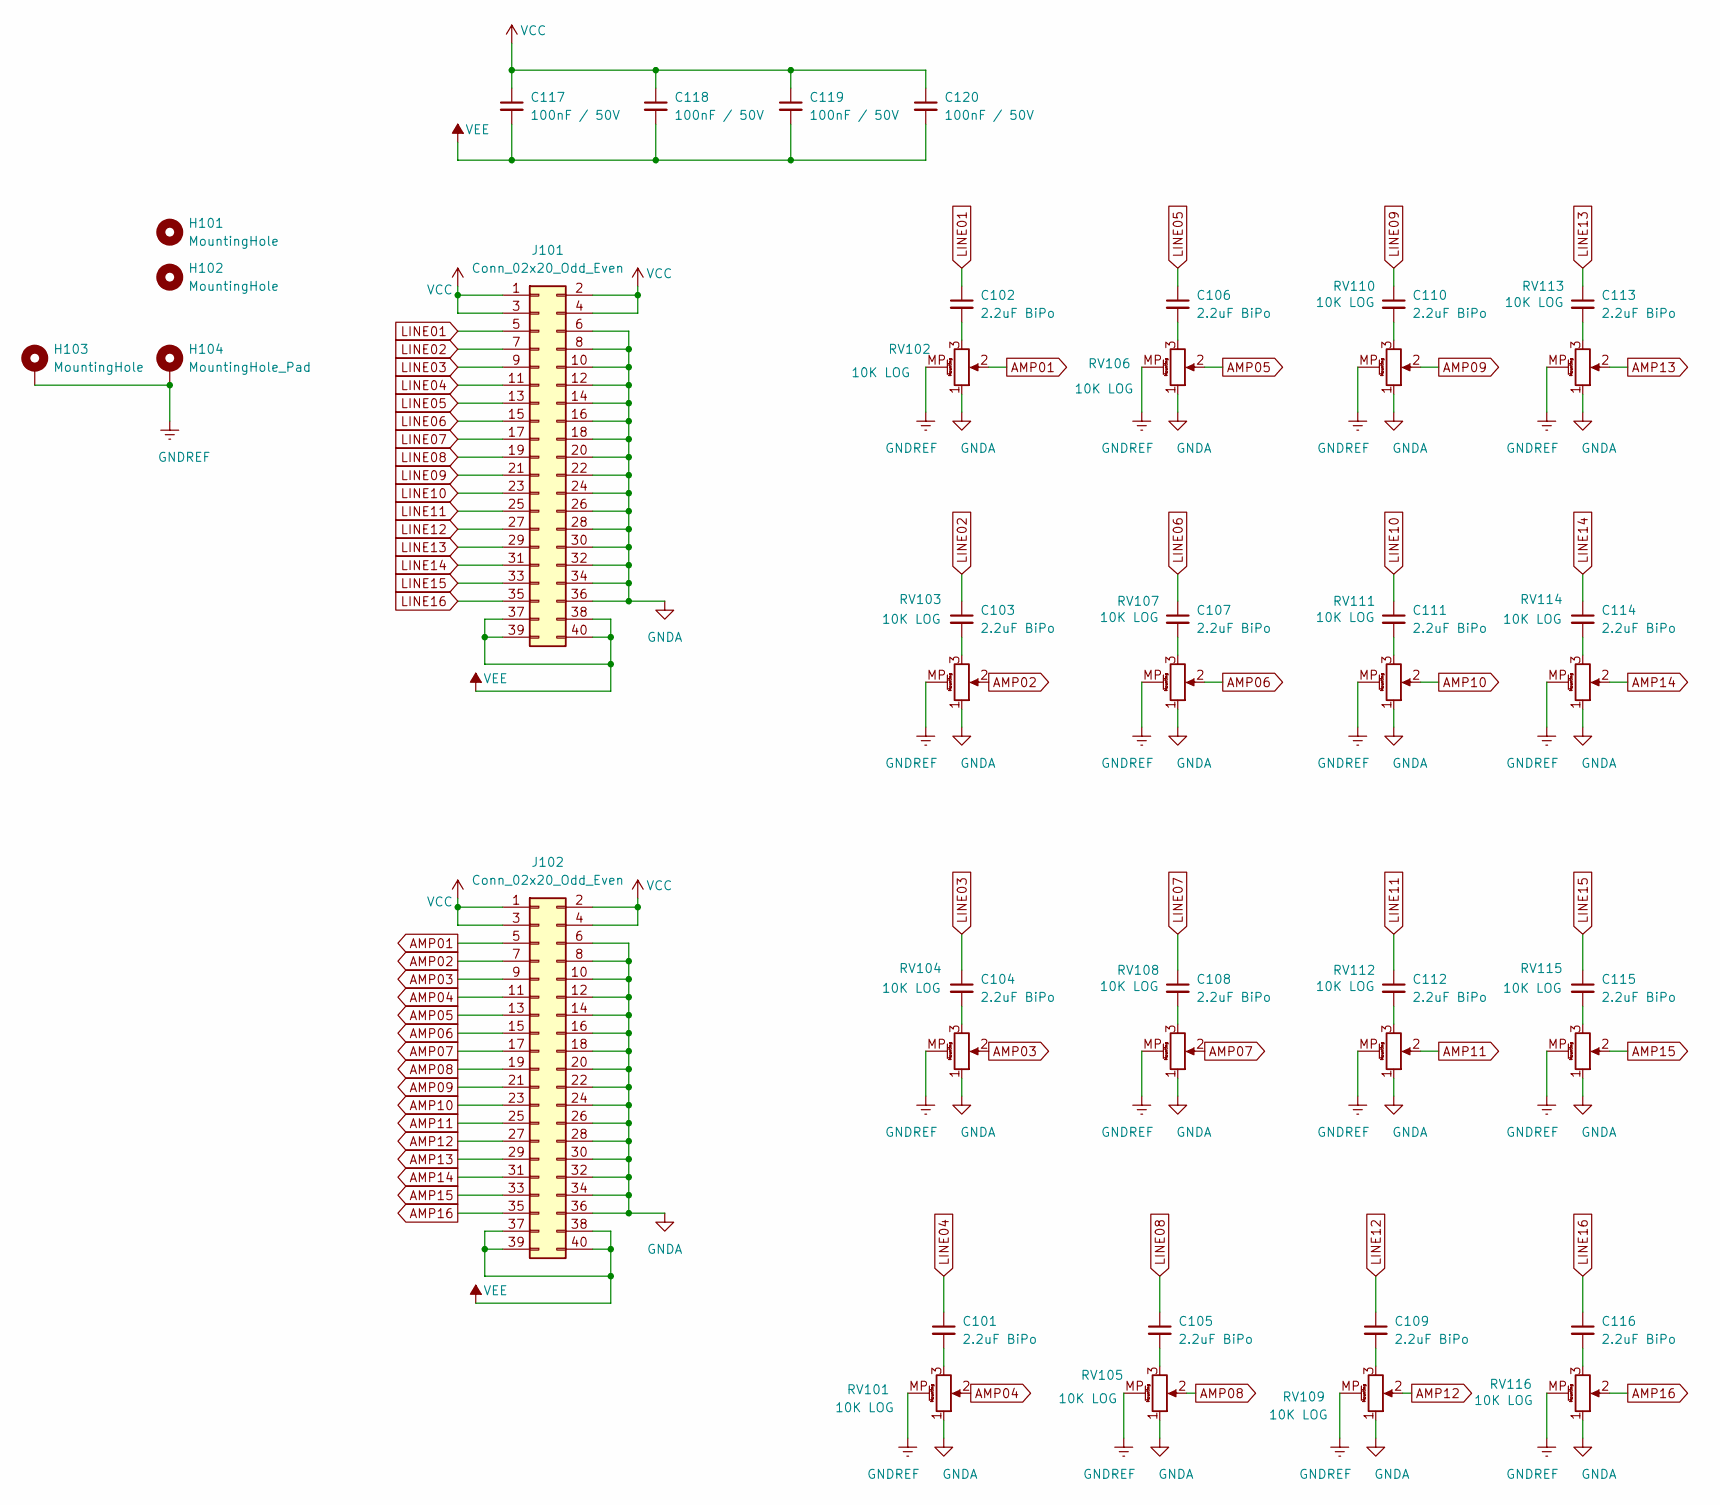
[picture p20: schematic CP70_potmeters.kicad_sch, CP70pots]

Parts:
C101, C102, C103, C104, C105, C106, C107, C108, C109, C110, C111, C112, C113, C114, C115, C116: 2.2uF BiPo; C_Radial_D5.0mm_H11.0mm_P2.00mm
C117, C118, C119, C120: 100nF / 50V; C_Disc_D6.0mm_W2.5mm_P5.00mm
H101, H102, H103: MountingHole; MountingHole_3.2mm_M3_Pad_Via
H104: MountingHole_Pad; MountingHole_3.2mm_M3_Pad_Via
J101, J102: Conn_02x20_Odd_Even; IDC-Header_2x20_P2.54mm_Latch_Vertical
RV101, RV102, RV103, RV104, RV105, RV106, RV107, RV108, RV109, RV110, RV111, RV112, RV113, RV114, RV115, RV116: 10K LOG; Potentiometer_Alps_RK09L_Single_Horizontal

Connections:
AMP01: J102.5, RV102.2
AMP02: J102.7, RV103.2
AMP03: J102.9, RV104.2
AMP04: J102.11, RV101.2
AMP05: J102.13, RV106.2
AMP06: J102.15, RV107.2
AMP07: J102.17, RV108.2
AMP08: J102.19, RV105.2
AMP09: J102.21, RV110.2
AMP10: J102.23, RV111.2
AMP11: J102.25, RV112.2
AMP12: J102.27, RV109.2
AMP13: J102.29, RV113.2
AMP14: J102.31, RV114.2
AMP15: J102.33, RV115.2
AMP16: J102.35, RV116.2
GNDA: J101.6, J101.8, J101.10, J101.12, J101.14, J101.16, J101.18, J101.20, J101.22, J101.24, J101.26, J101.28, J101.30, J101.32, J101.34, J101.36, J102.6, J102.8, J102.10, J102.12, J102.14, J102.16, J102.18, J102.20, J102.22, J102.24, J102.26, J102.28, J102.30, J102.32, J102.34, J102.36, RV101.1, RV102.1, RV103.1, RV104.1, RV105.1, RV106.1, RV107.1, RV108.1, RV109.1, RV110.1, RV111.1, RV112.1, RV113.1, RV114.1, RV115.1, RV116.1
GNDREF: H103.1, H104.1, RV101.MP (MountPin), RV102.MP (MountPin), RV103.MP (MountPin), RV104.MP (MountPin), RV105.MP (MountPin), RV106.MP (MountPin), RV107.MP (MountPin), RV108.MP (MountPin), RV109.MP (MountPin), RV110.MP (MountPin), RV111.MP (MountPin), RV112.MP (MountPin), RV113.MP (MountPin), RV114.MP (MountPin), RV115.MP (MountPin), RV116.MP (MountPin)
LINE01: C102.1, J101.5
LINE02: C103.1, J101.7
LINE03: C104.1, J101.9
LINE04: C101.1, J101.11
LINE05: C106.1, J101.13
LINE06: C107.1, J101.15
LINE07: C108.1, J101.17
LINE08: C105.1, J101.19
LINE09: C110.1, J101.21
LINE10: C111.1, J101.23
LINE11: C112.1, J101.25
LINE12: C109.1, J101.27
LINE13: C113.1, J101.29
LINE14: C114.1, J101.31
LINE15: C115.1, J101.33
LINE16: C116.1, J101.35
unnamed: C101.2, RV101.3
unnamed: C102.2, RV102.3
unnamed: C103.2, RV103.3
unnamed: C104.2, RV104.3
unnamed: C105.2, RV105.3
unnamed: C106.2, RV106.3
unnamed: C107.2, RV107.3
unnamed: C108.2, RV108.3
unnamed: C109.2, RV109.3
unnamed: C110.2, RV110.3
unnamed: C111.2, RV111.3
unnamed: C112.2, RV112.3
unnamed: C113.2, RV113.3
unnamed: C114.2, RV114.3
unnamed: C115.2, RV115.3
unnamed: C116.2, RV116.3
VCC: C117.1, C118.1, C119.1, C120.1, J101.1, J101.2, J101.3, J101.4, J102.1, J102.2, J102.3, J102.4
VEE: C117.2, C118.2, C119.2, C120.2, J101.37, J101.38, J101.39, J101.40, J102.37, J102.38, J102.39, J102.40

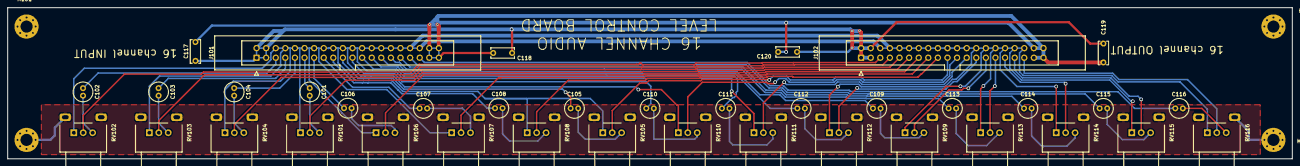
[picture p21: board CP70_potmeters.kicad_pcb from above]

Board: 2 copper layers, 340.0 x 40.0 mm, 42 parts (0 on the bottom side), 52 nets.

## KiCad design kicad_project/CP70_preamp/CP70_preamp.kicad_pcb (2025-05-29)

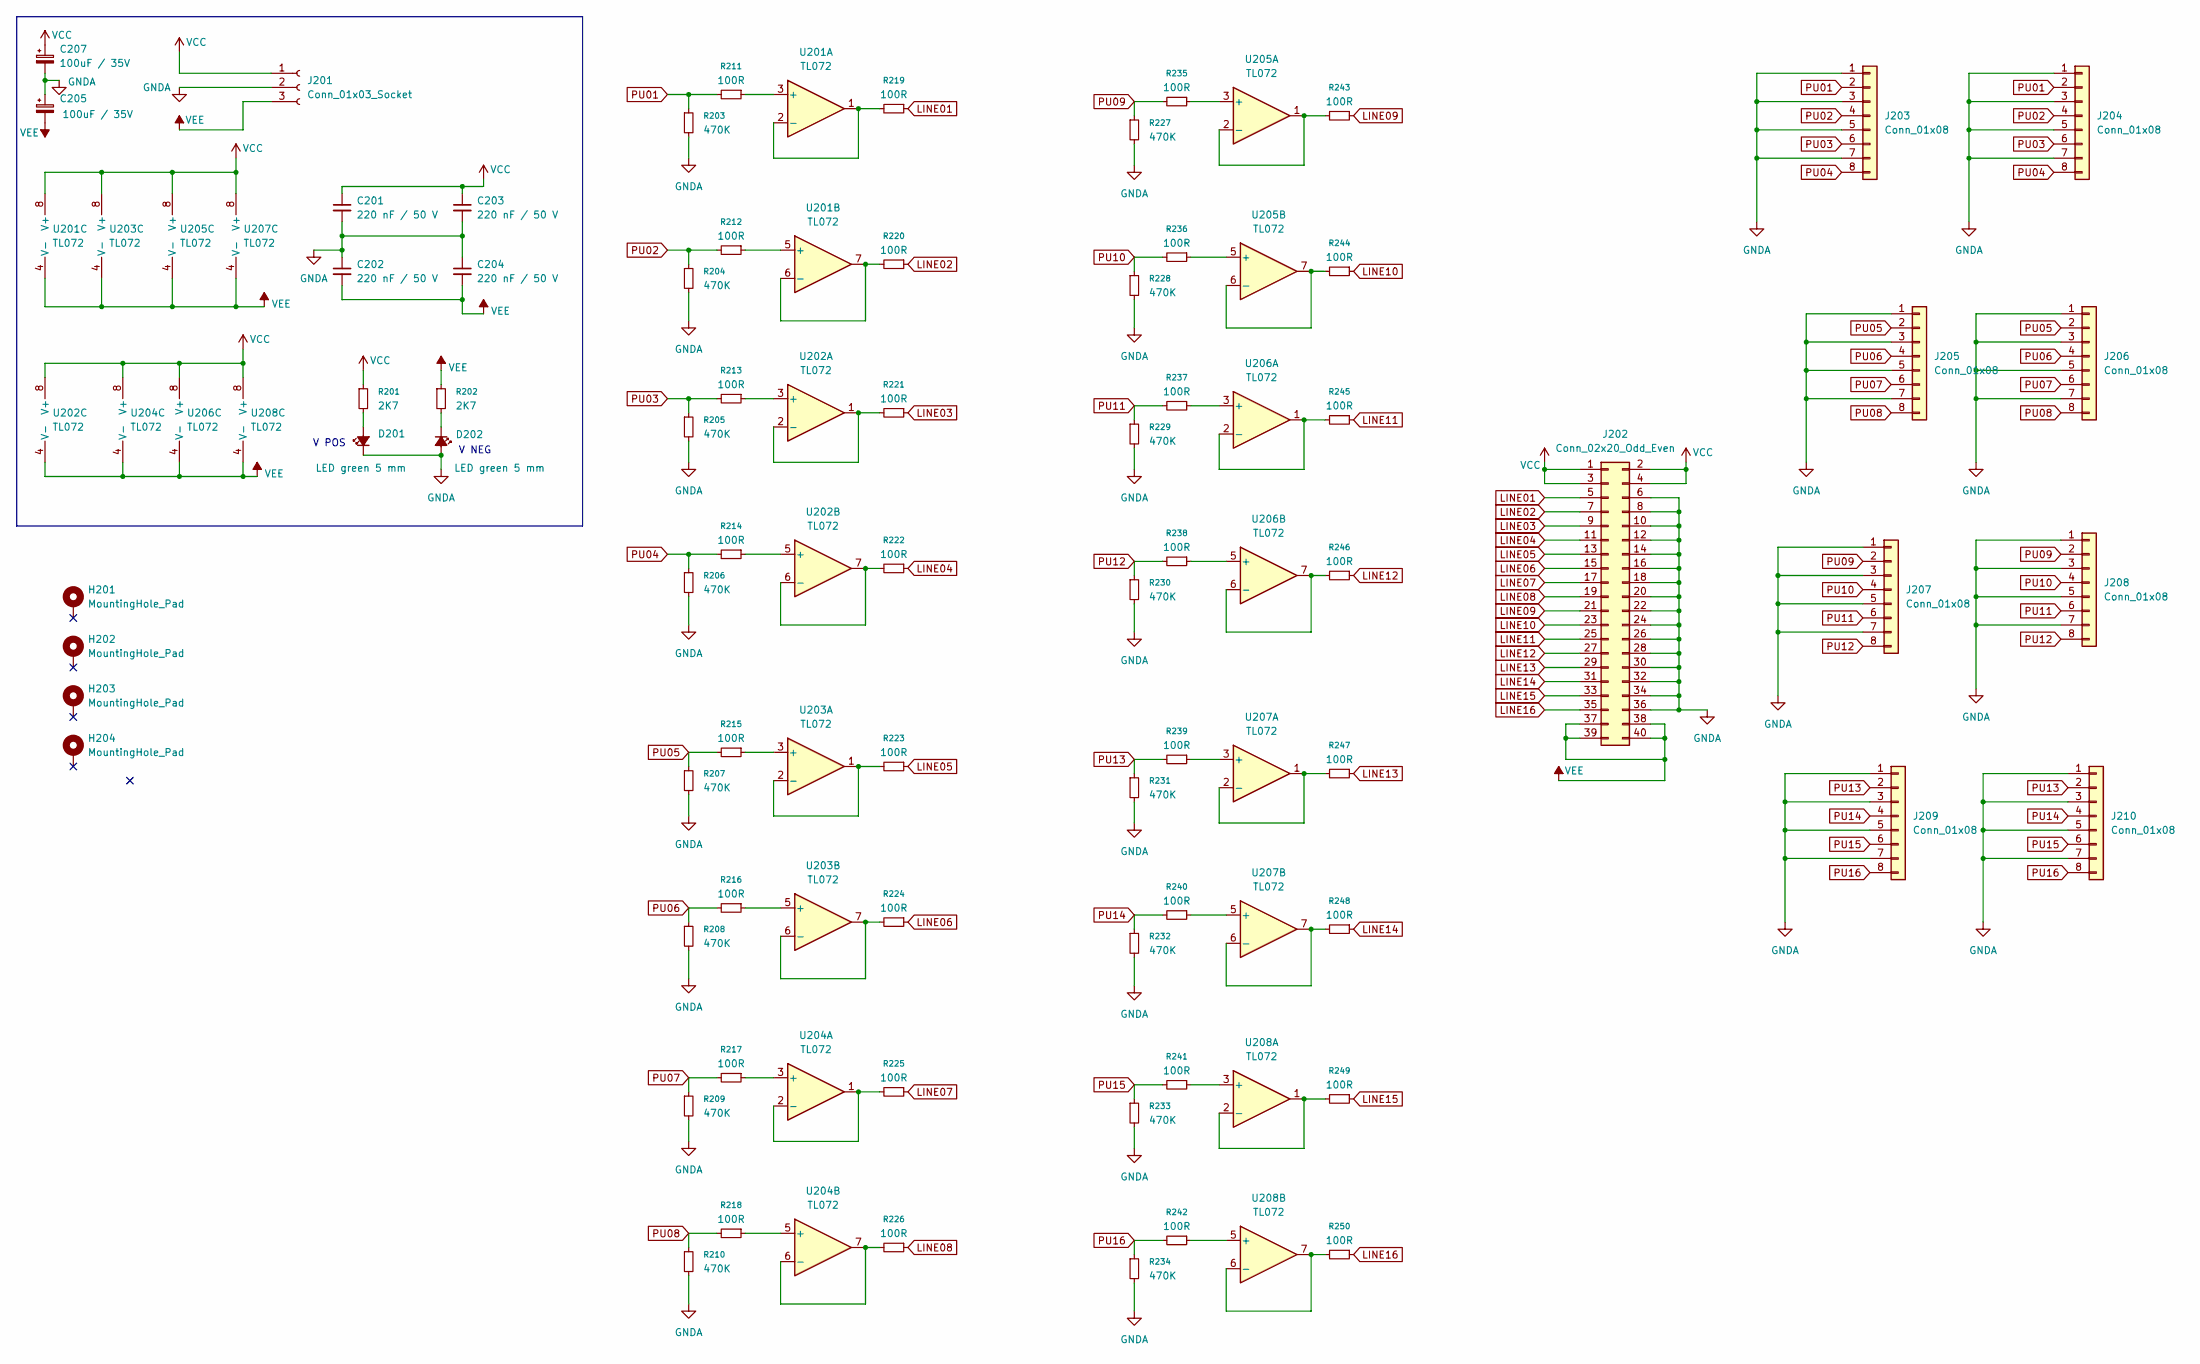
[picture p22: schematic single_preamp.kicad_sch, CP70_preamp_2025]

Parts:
C201, C202, C203, C204: 220 nF / 50 V; C_Disc_D6.0mm_W2.5mm_P5.00mm
C205, C207: 100uF / 35V; CP_Radial_D10.0mm_P5.00mm
D201, D202: LED green 5 mm; LED_D5.0mm
H201, H202, H203, H204: MountingHole_Pad; MountingHole_3.2mm_M3_Pad_Via
J201: Conn_01x03_Socket; PhoenixContact_MSTBVA_2,5_3-G-5,08_1x03_P5.08mm_Vertical
J202: Conn_02x20_Odd_Even
J203, J204, J205, J206, J207, J208, J209, J210: Conn_01x08; PinHeader_1x08_P2.54mm_Vertical
R201, R202: 2K7; R_Axial_DIN0207_L6.3mm_D2.5mm_P7.62mm_Horizontal
R203, R204, R205, R206, R207, R208, R209, R210, R227, R228, R229, R230, R231, R232, R233, R234: 470K; R_Axial_DIN0207_L6.3mm_D2.5mm_P7.62mm_Horizontal
R211, R212, R213, R214, R215, R216, R217, R218, R219, R220, R221, R222, R223, R224, R225, R226, R235, R236, R237, R238, R239, R240, R241, R242, R243, R244, R245, R246, R247, R248, R249, R250: 100R; R_Axial_DIN0207_L6.3mm_D2.5mm_P7.62mm_Horizontal
U201, U202, U203, U204, U205, U206, U207, U208: TL072; DIP-8_W7.62mm_LongPads

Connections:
GNDA: C201.2, C202.1, C203.2, C204.1, C205.1, C207.2, D201.1 (K), D202.2 (A), J201.2, J202.6, J202.8, J202.10, J202.12, J202.14, J202.16, J202.18, J202.20, J202.22, J202.24, J202.26, J202.28, J202.30, J202.32, J202.34, J202.36, J203.1, J203.3, J203.5, J203.7, J204.1, J204.3, J204.5, J204.7, J205.1, J205.3, J205.5, J205.7, J206.1, J206.3, J206.5, J206.7, J207.1, J207.3, J207.5, J207.7, J208.1, J208.3, J208.5, J208.7, J209.1, J209.3, J209.5, J209.7, J210.1, J210.3, J210.5, J210.7, R203.2, R204.2, R205.2, R206.2, R207.2, R208.2, R209.2, R210.2, R227.2, R228.2, R229.2, R230.2, R231.2, R232.2, R233.2, R234.2
LINE01: J202.5, R219.1
LINE02: J202.7, R220.1
LINE03: J202.9, R221.1
LINE04: J202.11, R222.1
LINE05: J202.13, R223.1
LINE06: J202.15, R224.1
LINE07: J202.17, R225.1
LINE08: J202.19, R226.1
LINE09: J202.21, R243.1
LINE10: J202.23, R244.1
LINE11: J202.25, R245.1
LINE12: J202.27, R246.1
LINE13: J202.29, R247.1
LINE14: J202.31, R248.1
LINE15: J202.33, R249.1
LINE16: J202.35, R250.1
unnamed: D201.2 (A), R201.2
unnamed: D202.1 (K), R202.2
unnamed: R211.1, U201.3 (+)
unnamed: R219.2, U201.1, U201.2 (-)
unnamed: R212.1, U201.5 (+)
unnamed: R220.2, U201.6 (-), U201.7
unnamed: R213.1, U202.3 (+)
unnamed: R221.2, U202.1, U202.2 (-)
unnamed: R214.1, U202.5 (+)
unnamed: R222.2, U202.6 (-), U202.7
unnamed: R215.1, U203.3 (+)
unnamed: R223.2, U203.1, U203.2 (-)
unnamed: R216.1, U203.5 (+)
unnamed: R224.2, U203.6 (-), U203.7
unnamed: R217.1, U204.3 (+)
unnamed: R225.2, U204.1, U204.2 (-)
unnamed: R218.1, U204.5 (+)
unnamed: R226.2, U204.6 (-), U204.7
unnamed: R235.1, U205.3 (+)
unnamed: R243.2, U205.1, U205.2 (-)
unnamed: R236.1, U205.5 (+)
unnamed: R244.2, U205.6 (-), U205.7
unnamed: R237.1, U206.3 (+)
unnamed: R245.2, U206.1, U206.2 (-)
unnamed: R238.1, U206.5 (+)
unnamed: R246.2, U206.6 (-), U206.7
unnamed: R239.1, U207.3 (+)
unnamed: R247.2, U207.1, U207.2 (-)
unnamed: R240.1, U207.5 (+)
unnamed: R248.2, U207.6 (-), U207.7
unnamed: R241.1, U208.3 (+)
unnamed: R249.2, U208.1, U208.2 (-)
unnamed: R242.1, U208.5 (+)
unnamed: R250.2, U208.6 (-), U208.7
PU01: J203.2, J204.2, R203.1, R211.2
PU02: J203.4, J204.4, R204.1, R212.2
PU03: J203.6, J204.6, R205.1, R213.2
PU04: J203.8, J204.8, R206.1, R214.2
PU05: J205.2, J206.2, R207.1, R215.2
PU06: J205.4, J206.4, R208.1, R216.2
PU07: J205.6, J206.6, R209.1, R217.2
PU08: J205.8, J206.8, R210.1, R218.2
PU09: J207.2, J208.2, R227.1, R235.2
PU10: J207.4, J208.4, R228.1, R236.2
PU11: J207.6, J208.6, R229.1, R237.2
PU12: J207.8, J208.8, R230.1, R238.2
PU13: J209.2, J210.2, R231.1, R239.2
PU14: J209.4, J210.4, R232.1, R240.2
PU15: J209.6, J210.6, R233.1, R241.2
PU16: J209.8, J210.8, R234.1, R242.2
VCC: C201.1, C203.1, C207.1, J201.1, J202.1, J202.2, J202.3, J202.4, R201.1, U201.8 (V+), U202.8 (V+), U203.8 (V+), U204.8 (V+), U205.8 (V+), U206.8 (V+), U207.8 (V+), U208.8 (V+)
VEE: C202.2, C204.2, C205.2, J201.3, J202.37, J202.38, J202.39, J202.40, R202.1, U201.4 (V-), U202.4 (V-), U203.4 (V-), U204.4 (V-), U205.4 (V-), U206.4 (V-), U207.4 (V-), U208.4 (V-)

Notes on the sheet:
V NEG
V POS

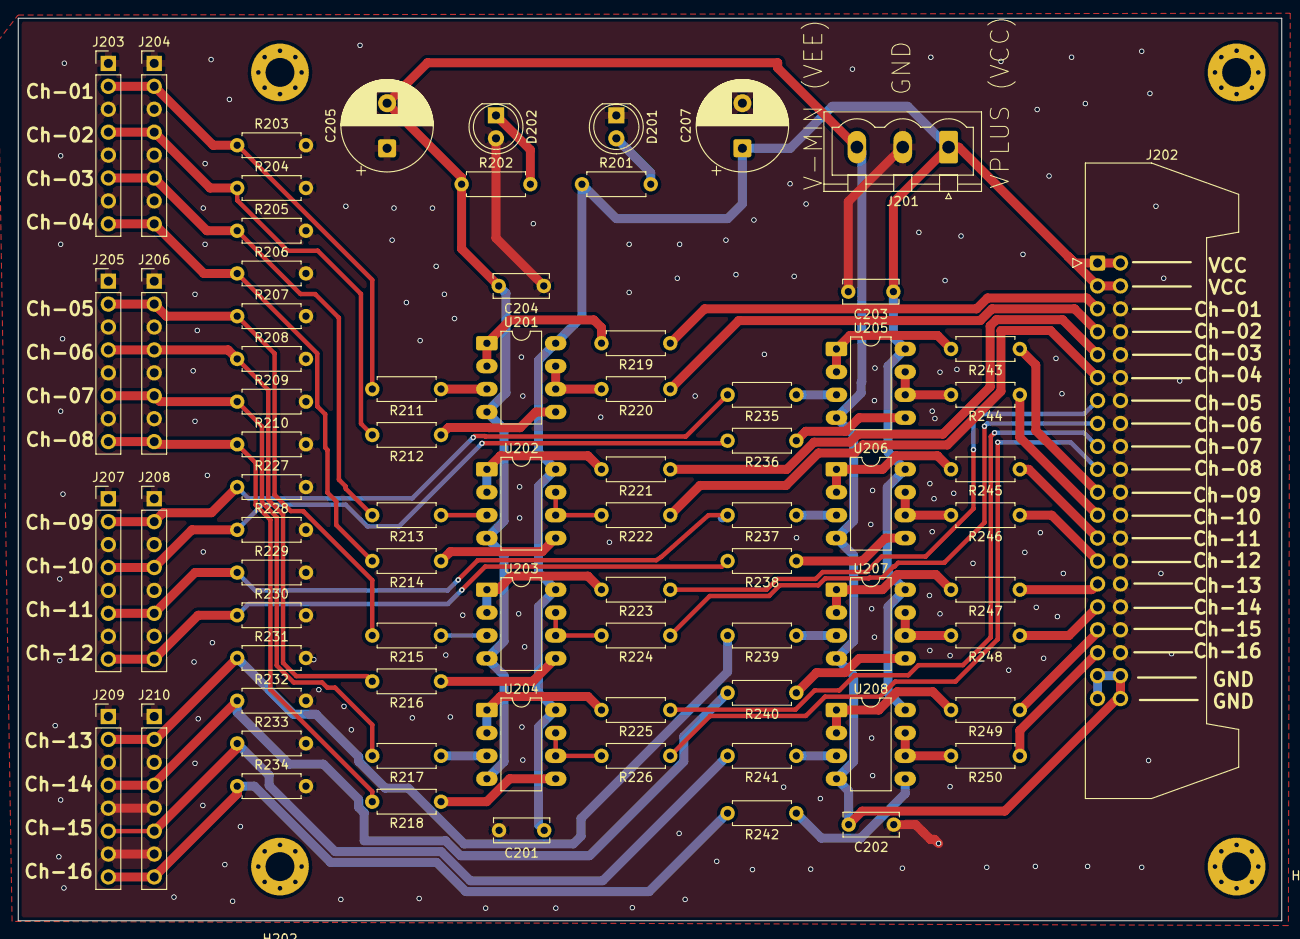
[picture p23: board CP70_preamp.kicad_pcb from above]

Board: 2 copper layers, 140.0 x 100.0 mm, 80 parts (0 on the bottom side), 69 nets.

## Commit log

2025-05-29 initial file and directory structure uploaded
    [CP70_preamp.kicad_pcb, CP70_preamp.kicad_sch]
2025-05-29 design of 16 channel pre amp, including circuit board, ordered. Gerbers in repository.
    [CP70_preamp.dsn, CP70_preamp.kicad_pcb, CP70_preamp.kicad_sch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]
2025-05-30 Update README.md
    update milestones, parts ordered, pcb ordered and designed
2025-05-30 adding images of PCB and piano
2025-07-18 Add files via upload
    first set of pre-amp and pot board tested ok
2025-07-18 adding potmeter board first version
    [CP70_potmeters-B_Cu.gbr, CP70_potmeters-B_Mask.gbr, CP70_potmeters-B_Paste.gbr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]
2025-08-14 two new boards, needed for breakout of flat cable to power amps and second is flat cable to other flat cable
    [CP70_front_flatcable-B_Cu.gbr, CP70_front_flatcable-B_Mask.gbr, CP70_front_flatcable-B_Paste.gbr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]
